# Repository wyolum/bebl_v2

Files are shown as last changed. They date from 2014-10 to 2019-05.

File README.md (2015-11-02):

bebl_v2
=======

"Bar End Brake Light" , redux. v2 of Justin's original BEBL with mods.

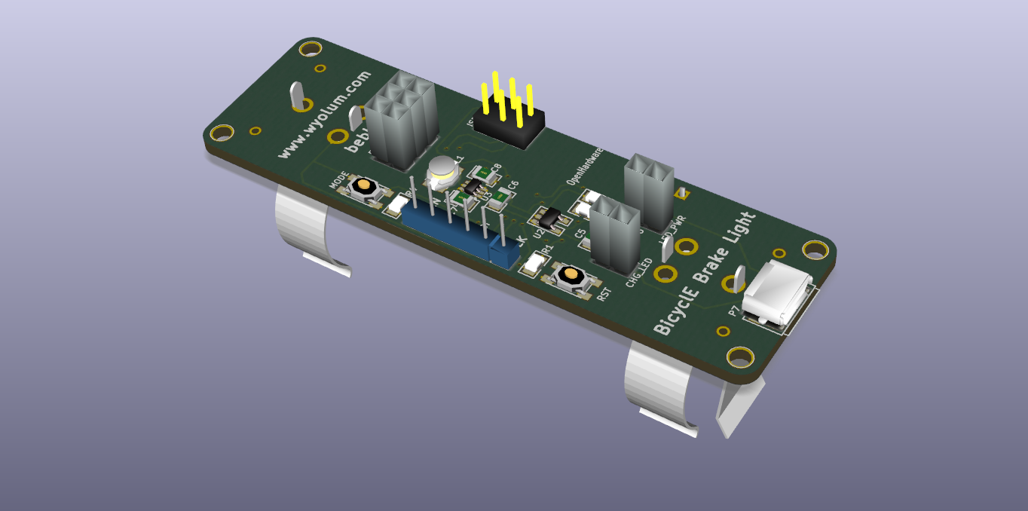
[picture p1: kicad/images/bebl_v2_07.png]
bebl main board


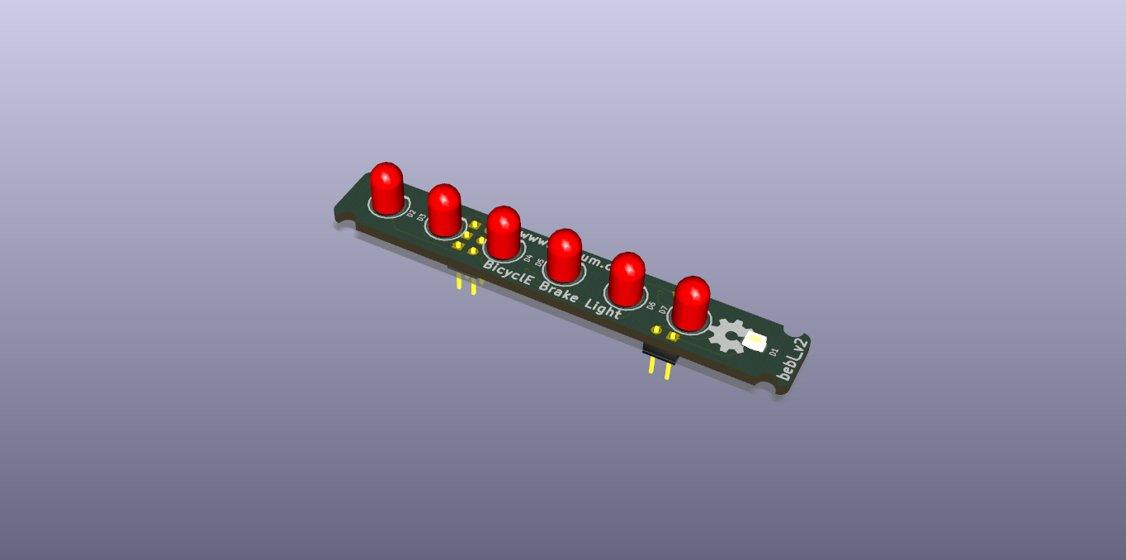
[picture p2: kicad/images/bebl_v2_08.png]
bebl LED board


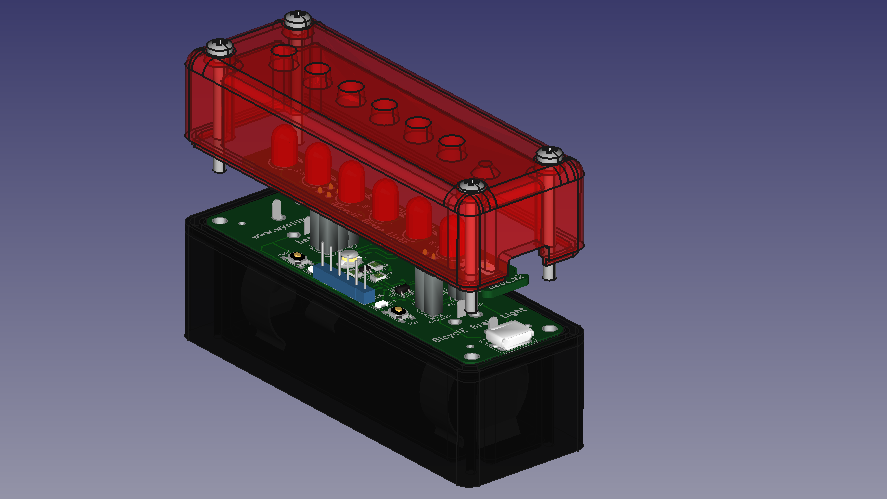
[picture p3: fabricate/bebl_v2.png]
bebl with 3D printed housing


License
-------
[CERN Open Hardware Licence v1.2 ]

[CERN Open Hardware Licence v1.2 ]:http://www.ohwr.org/attachments/2388/cern_ohl_v_1_2.txt

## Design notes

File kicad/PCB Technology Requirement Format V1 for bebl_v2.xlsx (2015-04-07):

深圳矽递科技有限公司Seeed Technology Inc.
PCB Technology Requirement Format
PCB Name & Version
PCB Material PCB板材： | (Rigid)FR－4
PCB Size PCB大小： | mm | ( 80 ) × ( 24 )
PCB Layer PCB层数： | 2
Thickness PCB厚度：
 |  | 1.6mm
Copper Weight铜厚： | 1oz
PCB Colour阻焊颜色： |  | White白色
Silkscreen字符颜色： |  | Black黑色
Pads Finished焊盘喷镀： | (Hasl-lead free)无铅喷锡
Via solder mask阻焊覆盖： |  | solder mask opening过孔开窗
Minimum trace/space (mm)最小线宽 | 0.178mm | Minimum hole size (mm)最小孔径 | 0.508mm
Special requirements特殊工艺： | Yes | (Put requirements here)
Comment: | PCB is in two parts 80 x 24 mm 74 x 11 mm

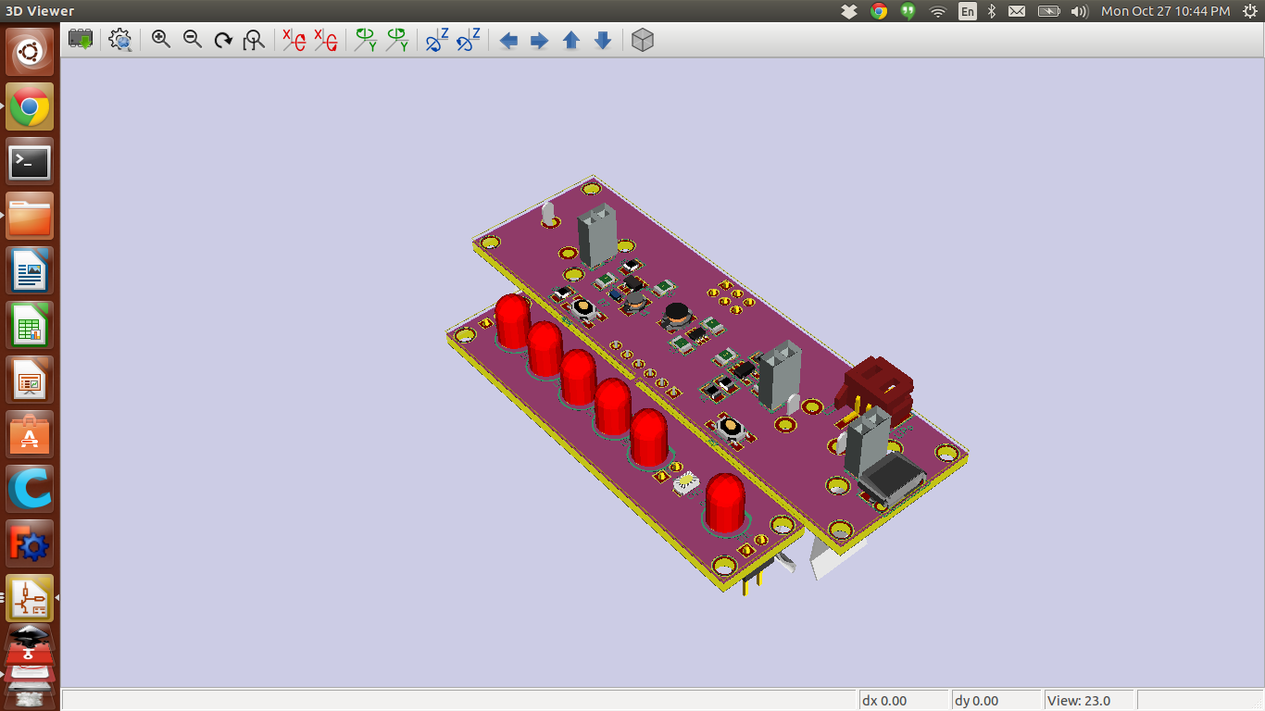
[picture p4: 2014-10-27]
kicad/images/bebl_v2_04.png

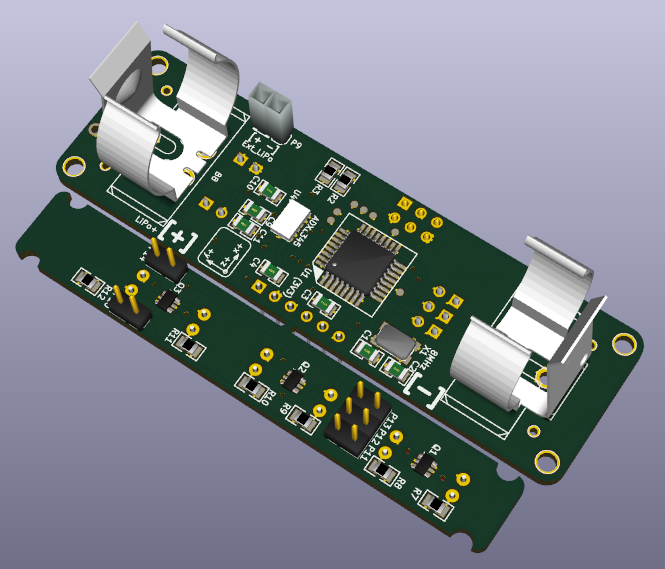
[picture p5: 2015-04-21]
kicad/images/bebl_v2_05.png

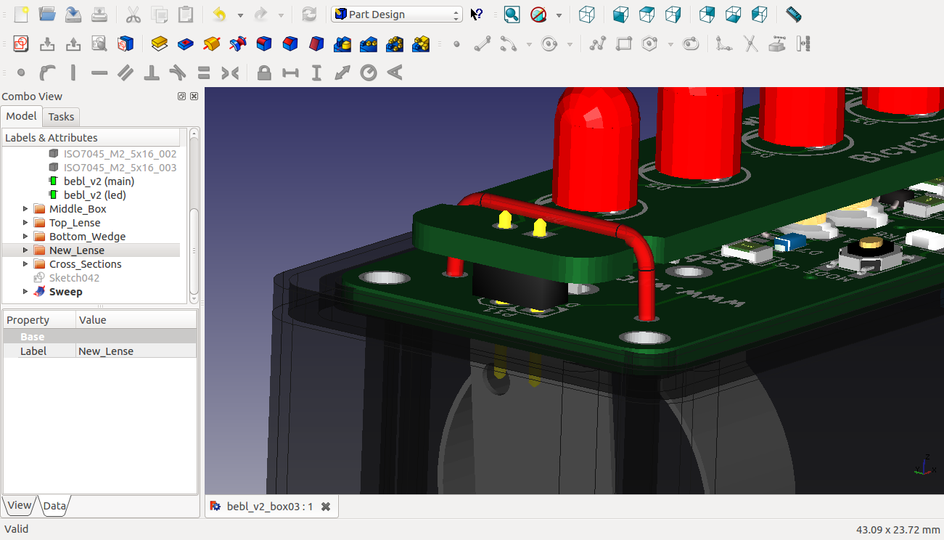
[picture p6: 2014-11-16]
kicad/images/bebl_v2_RedWireAnchor.png

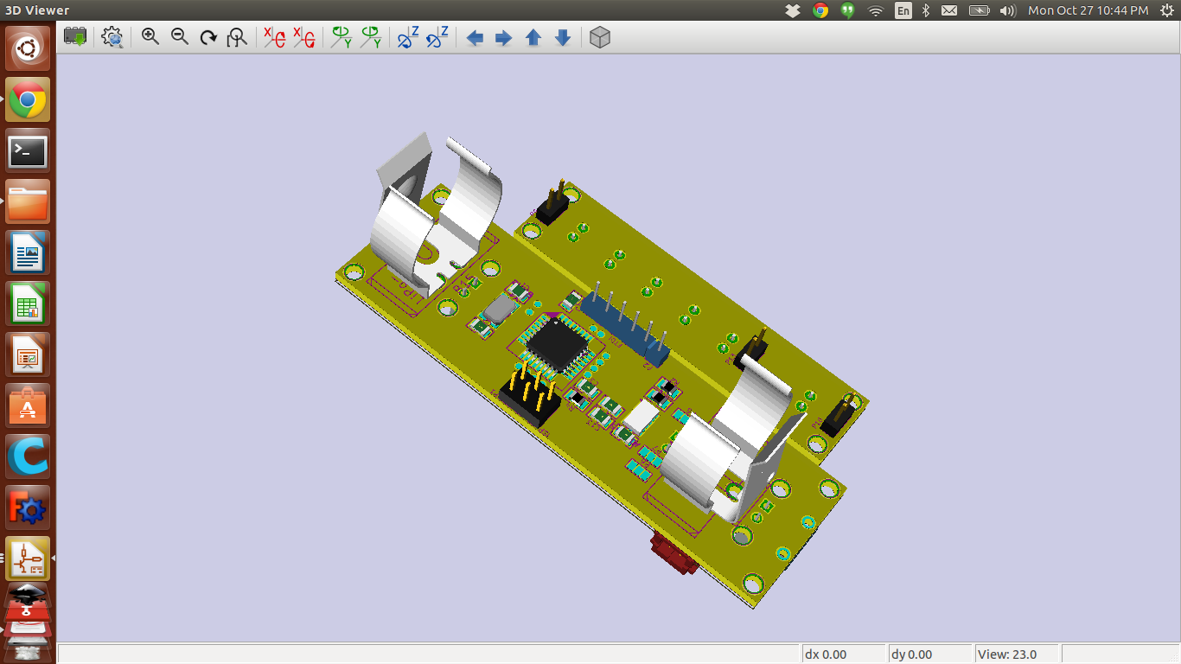
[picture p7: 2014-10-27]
kicad/images/bebl_v2_03.png

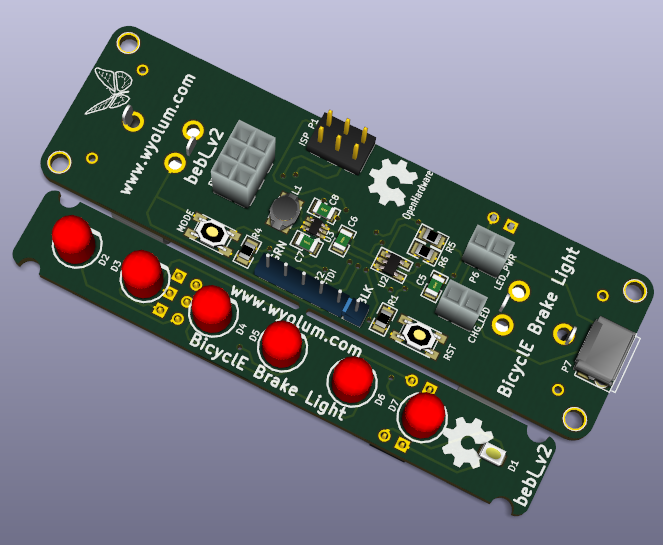
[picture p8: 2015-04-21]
kicad/images/bebl_v2_06.png

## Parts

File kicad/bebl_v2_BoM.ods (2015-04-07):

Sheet: Sheet1
Reference | Qty | Catalog | Description | Value | Package | Footprint | Manufacturer | Mfg. P/N | Distributor | Dist. P/N | Link | Price/1 | Price/100
 |  |  |  |  |  |  |  |  |  |  |  | 20.19 | 14.03 | 34.28 | 23.54
B8, B9 | 2 |  | BATTERY CLIP 18MM 18650 CELL | LiPo+ | PCB, Through Hole | batt_clip | Keystone Electronics | 54 | Digikey | KEY1007-ND | http://www.digikey.com/product-detail/en/54/KEY1007-ND/2254090 | 0.68 | 0.40 | 1.36 | 0.81
C1, C2 | 2 |  | CAP CER 22PF 100V 5% NP0 0805 | 22pF | 0805 (2012 Metric) | c_0805 | Samsung Electro-Mechanics America, Inc | CL21C220JCANNNC | Digikey | 1276-2607-1-ND | http://www.digikey.com/product-detail/en/CL21C220JCANNNC/1276-2607-1-ND/3890693 | 0.10 | 0.03 | 0.20 | 0.06
C3, C4, C11, C10 | 4 |  | CAP CER 0.1UF 25V 10% X7R 0805 | 100nF | 0805 (2012 Metric) | c_0805 | Samsung Electro-Mechanics America, Inc | CL21B104KACNNNC | Digikey | 1276-1099-1-ND | http://www.digikey.com/product-detail/en/CL21B104KACNNNC/1276-1099-1-ND/3889185 | 0.10 | 0.02 | 0.40 | 0.08
C5, C6 | 2 |  | CAP CER 4.7UF 10V 10% X7R 0805 | 4u7 | 0805 (2012 Metric) | c_0805 | Samsung Electro-Mechanics America, Inc | CL21B475KPFNNNE | Digikey | 1276-2972-1-ND | http://www.digikey.com/product-detail/en/CL21B475KPFNNNE/1276-2972-1-ND/3891058 | 0.20 | 0.07 | 0.40 | 0.14
C7, C8, C9 | 3 |  | CAP CER 10UF 16V 10% X7R 0805 | 10uF | 0805 (2012 Metric) | c_0805 | Samsung Electro-Mechanics America, Inc | CL21B106KOQNNNE | Digikey | 1276-2872-1-ND | http://www.digikey.com/product-detail/en/CL21B106KOQNNNE/1276-2872-1-ND/3890958 | 0.30 | 0.12 | 0.90 | 0.37
D1 | 1 |  | LED CHIPLED 588NM YLW 0805 SMD | CHG | 0805 (2012 Metric) | LED-0805 | OSRAM Opto Semiconductors Inc | LY R976-PS-36 | Digikey | 475-2560-1-ND | http://www.digikey.com/product-detail/en/LY%20R976-PS-36/475-2560-1-ND/1802687 | 0.09 | 0.06 | 0.09 | 0.06
D2, D3, D4, D5, D6, D7 | 6 |  | LED, 5mm, high intensity | LED_P, LED_D, LED_B | 5mm Through Hole | LED-5MM | CHINA YOUNG SUN LED TECHNOLOGY CO., LTD. | YSL-R531R3C-A13 | Sparkfun | COM-00528 | https://www.sparkfun.com/products/528 | 0.95 | 0.76 | 5.70 | 4.56
L1 | 1 |  | FIXED IND 4.7uH 1.5A 144 mOHM | 4u7 | 1212 (3030 Metric) | Inductor_LQH3NPN | Murata Electronics North America | LQH3NPN4R7MJRL | Digikey | 490-9579-1-ND | http://www.digikey.com/product-detail/en/LQH3NPN4R7MJRL/490-9579-1-ND/4864756 | 0.48 | 0.31 | 0.48 | 0.31
P1 | 1 |  | CONN HEADER 6POS .100 STR TIN | ISP | Dual row, 0.1”, Male Header | Dual row, 0.1”, Male Header | FCI | 67996-406HLF | Digikey | 609-3218-ND | http://www.digikey.com/product-detail/en/67996-406HLF/609-3218-ND/1878478 | 0.26 | 0.17 | 0.26 | 0.17
P2,P10,P11,P12,P13,P14 | 6 |  | CONN HEADER .100" SNGL STR 40POS | FTDI,LED_CHG,LED_1,LED_2,LED_3,LED_PWR | Single row, 0.1”, Male Header | Single row, 0.1”, Male Header | Sullins Connector Solutions | PREC040SAAN-RC | Digikey | S1012EC-40-ND | http://www.digikey.com/product-detail/en/PREC040SAAN-RC/S1012EC-40-ND/2774814 | 0.56 | 0.42 | 3.36 | 2.49
P3,P4,P5,P6,P8,P9 | 6 |  | CONN SOCKET SGL VERT 2POS GOLD | LED_CHG,LED_1,LED_2,LED_3,LED_PWR,Ext_Lipo | Single row, 0.1”, Female Socket | Single row, 0.1”, Female Socket | 3M | 960102-6202-AR | Digikey | 3M9513-ND | http://www.digikey.com/product-detail/en/960102-6202-AR/3M9513-ND/2071554 | 0.51 | 0.37 | 3.06 | 2.21
P7 | 1 |  | CONN USB MICRO B RECPT SMT R/A | USB-Micro | Surface Mount, Right Angle, Horizontal | Surface Mount, Right Angle, Horizontal | SunTech | ST-USB-001G | seeed Studio | 320010000 | http://www.seeedstudio.com/depot/index.php?main_page=opl_info&opl_id=331 | 0.46 | 0.30 | 0.46 | 0.30
Q1, Q2, Q3 | 3 |  | TRANS 2NPN 45V 0.1A SOT363 | BC847 | 6-TSSOP, SC-88, SOT-363 | SOT23-6 | ON Semiconductor | TRANS 2NPN 45V 0.1A SOT363 | Digikey | BC847BDW1T3GOSCT-ND | http://www.digikey.com/product-detail/en/BC847BDW1T3G/BC847BDW1T3GOSCT-ND/2120552 | 0.24 | 0.12 | 0.72 | 0.37
R1,R2,R3,R4 | 4 |  | RES 10K OHM 1/8W 1% 0805 | 10k | 0805 (2012 Metric) | r_0805 | Stackpole Electronics Inc | RMCF0805FT10K0 | Digikey | RMCF0805FT10K0CT-ND | http://www.digikey.com/product-detail/en/RMCF0805FT10K0/RMCF0805FT10K0CT-ND/1942435 | 0.10 | 0.01 | 0.40 | 0.05
R5 | 1 |  | RES 150 OHM 1/8W 1% 0805 | 150E | 0805 (2012 Metric) | r_0805 | Stackpole Electronics Inc | RMCF0805FT150R | Digikey | RMCF0805FT150RCT-ND | http://www.digikey.com/product-detail/en/RMCF0805FT150R/RMCF0805FT150RCT-ND/1942337 | 0.10 | 0.01 | 0.10 | 0.01
R6 | 1 |  | RES 2K OHM 1/8W 1% 0805 | 2k | 0805 (2012 Metric) | r_0805 | Stackpole Electronics Inc | RMCF0805FT2K00 | Digikey | RMCF0805FT2K00CT-ND | http://www.digikey.com/product-detail/en/RMCF0805FT2K00/RMCF0805FT2K00CT-ND/1942383 | 0.10 | 0.01 | 0.10 | 0.01
R7, R8, R9, R10, R11, R12 | 6 |  | RES SMD 22 OHM 1% 1/8W 0805 |  | 0805 (2012 Metric) | r_0805 | Stackpole Electronics Inc | RMCF0805FT22R0 | Digikey | RMCF0805FT22R0CT-ND | http://www.digikey.com/product-detail/en/RMCF0805FT22R0/RMCF0805FT22R0CT-ND/2418324 | 0.10 | 0.01 | 0.60 | 0.07
SW1, SW2 | 2 |  | SWITCH TACTILE SPST-NO 0.02A 15V | RST, MODE | 4.70mm x 3.50mm | Switch_SMT | Panasonic Electronic Components | EVQ-P2402M | Digikey | P11080SCT-ND | http://www.digikey.com/product-detail/en/EVQ-P2402M/P11080SCT-ND/304157 | 0.83 | 0.63 | 1.66 | 1.25
U1 | 1 |  | IC MCU 8BIT 32KB FLASH 32TQFP | ATMEGA328P | 32-TQFP | TQFP32 | Atmel | ATMEGA328P-AU | Digikey | ATMEGA328P-AU-ND | http://www.digikey.com/product-detail/en/ATMEGA328P-AU/ATMEGA328P-AU-ND/1832260 | 3.61 | 2.64 | 3.61 | 2.64
U2 | 1 |  | IC CONTROLLR LI-ION 4.2V SOT23-5 | MCP73831 | SC-74A, SOT-753 | SOT23-5 | Microchip Technology | MCP73831T-2ACI/OT | Digikey | MCP73831T-2ACI/OTCT-ND | http://www.digikey.com/product-detail/en/MCP73831T-2ACI%2FOT/MCP73831T-2ACI%2FOTCT-ND/1979802 | 0.67 | 0.42 | 0.67 | 0.42
U3 | 1 |  | IC REG BOOST SYNC 3.3V SC70-6 | TPS61221DCK | 6-TSSOP, SC-88, SOT-363 | SOT23-6_LDO | Texas Instruments | TPS61221DCKT | Digikey | 296-24171-1-ND | http://www.digikey.com/product-search/en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 | 1.61 | 1.12 | 1.61 | 1.12
U4 | 1 |  | IC ACCEL SPI/I2C 3AX 3G 14LGA | ADXL345 | 14-VFLGA | ADXL345 | Analog Devices Inc | ADXL345BCCZ | Digikey | ADXL345BCCZ-ND | http://www.digikey.com/product-detail/en/ADXL345BCCZ/ADXL345BCCZ-ND/2034829 | 7.32 | 5.41 | 7.32 | 5.41
X1 | 1 |  | CRYSTAL 8MHZ 18PF SMD | 8MHz | 4-SMD, No Lead (DFN, LCC) | Xtal_SMD4 | TXC CORPORATION | 7B-8.000MAAJ-T | Digikey | 887-1452-1-ND | http://www.digikey.com/product-detail/en/7B-8.000MAAJ-T/887-1452-1-ND/2627020 | 0.82 | 0.60 | 0.82 | 0.60

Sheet: PCB
Id | Designator | Package | Quantity | Designation
1 | B8 | batt_clip | 1 | LiPo
2 | B9 | batt_clip | 1 | LiPo-
3 | C1,C2 | c_0805 | 2 | 22p
4 | C3,C4 | c_0805 | 2 | 100n
5 | C5,C6 | c_0805 | 2 | 4u7
6 | C7,C8,C9 | c_0805 | 3 | 10uF
7 | C11,C10 | c_0805 | 2 | 100nF
8 | D1 | LED-0805 | 1 | CHG
9 | D2,D3,D5,D6 | LED-5MM | 4 | LED_P
10 | D4 | LED-5MM | 1 | LED_D
11 | D7 | LED-5MM | 1 | LED_B
12 | L1 | Inductor_LQH3NPN | 1 | 4u7
13 | P1 | Header_3x2_ISP | 1 | ISP
14 | P2 | PIN_ARRAY-6X1 | 1 | FTDI
15 | P3 | pin_socket_2 | 1 | LED_1
16 | P4 | pin_socket_2 | 1 | LED_2
17 | P5 | pin_socket_2 | 1 | LED_3
18 | P6 | pin_socket_2 | 1 | LED_PWR
19 | P7 | USB_B_Micro | 1 | USB-Micro
20 | P8 | pin_socket_2 | 1 | CHG_LED
21 | P9 | pin_socket_2 | 1 | Ext_LiPo
22 | P10 | pin_strip_2 | 1 | LED_CHG
23 | P11 | pin_strip_2 | 1 | LED_1
24 | P12 | pin_strip_2 | 1 | LED_2
25 | P13 | pin_strip_2 | 1 | LED_3
26 | P14 | pin_strip_2 | 1 | LED_PWR
27 | Q1,Q2,Q3 | SOT23-6 | 3 | BC847BDW1T1G
28 | R1,R2,R3,R4 | r_0805 | 4 | 10k
29 | R5 | r_0805 | 1 | 150E
30 | R6 | r_0805 | 1 | 2k
31 | R7,R8,R9,R10,R11,R12 | r_0805 | 6 | 22E
32 | SW1 | Switch_SMT | 1 | RST
33 | SW2 | Switch_SMT | 1 | MODE
34 | U1 | TQFP32 | 1 | ATMEGA328P
35 | U2 | SOT23-5 | 1 | MCP73831
36 | U3 | SOT23-6_LDO | 1 | TPS61221DCK
37 | U4 | ADXL345 | 1 | ADXL345
38 | X1 | Xtal_SMD4 | 1 | 8MHz
39 | B1,B2,B3,B4,B5,B6,B7 | breakout_smd | 7 | I/O
40 | G***,G*** | OSHW_6mm | 2 | LOGO
41 | G1 | Logo-WL3 | 1 | Logo-WL3
42 | SC1,SC2,SC3,SC4,SC5,SC6,SC7,SC8 | screw_3mm | 8 | SCREW

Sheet: SCH
Reference | Value | Footprint
B8 | LiPo | bebl_v2_pretty:batt_clip
B9 | LiPo- | bebl_v2_pretty:batt_clip
C1 | 22p | bebl_v2_pretty:c_0805
C2 | 22p | bebl_v2_pretty:c_0805
C3 | 100n | bebl_v2_pretty:c_0805
C4 | 100n | bebl_v2_pretty:c_0805
C5 | 4u7 | bebl_v2_pretty:c_0805
C6 | 4u7 | bebl_v2_pretty:c_0805
C7 | 10uF | bebl_v2_pretty:c_0805
C8 | 10uF | bebl_v2_pretty:c_0805
C9 | 10uF | bebl_v2_pretty:c_0805
C10 | 100nF | bebl_v2_pretty:c_0805
C11 | 100nF | bebl_v2_pretty:c_0805
D1 | CHG | bebl_v2_pretty:LED-0805
D2 | LED_P | bebl_v2_pretty:LED-5MM
D3 | LED_P | bebl_v2_pretty:LED-5MM
D4 | LED_D | bebl_v2_pretty:LED-5MM
D5 | LED_P | bebl_v2_pretty:LED-5MM
D6 | LED_P | bebl_v2_pretty:LED-5MM
D7 | LED_B | bebl_v2_pretty:LED-5MM
L1 | 4u7 | bebl_v2_pretty:Inductor_LQH3NPN
P1 | ISP | bebl_v2_pretty:Header_3x2_ISP
P2 | FTDI | bebl_v2_pretty:PIN_ARRAY-6X1
P3 | LED_1 | bebl_v2_pretty:pin_socket_2
P4 | LED_2 | bebl_v2_pretty:pin_socket_2
P5 | LED_3 | bebl_v2_pretty:pin_socket_2
P6 | LED_PWR | bebl_v2_pretty:pin_socket_2
P7 | USB-Micro | bebl_v2_pretty:USB_B_Micro
P8 | CHG_LED | bebl_v2_pretty:pin_socket_2
P9 | Ext_LiPo | bebl_v2_pretty:pin_socket_2
P10 | LED_CHG | bebl_v2_pretty:pin_strip_2
P11 | LED_1 | bebl_v2_pretty:pin_strip_2
P12 | LED_2 | bebl_v2_pretty:pin_strip_2
P13 | LED_3 | bebl_v2_pretty:pin_strip_2
P14 | LED_PWR | bebl_v2_pretty:pin_strip_2
Q1 | BC847BDW1T1G | bebl_v2_pretty:SOT23-6
Q2 | BC847BDW1T1G | bebl_v2_pretty:SOT23-6
Q3 | BC847BDW1T1G | bebl_v2_pretty:SOT23-6
R1 | 10k | bebl_v2_pretty:r_0805
R2 | 10k | bebl_v2_pretty:r_0805
R3 | 10k | bebl_v2_pretty:r_0805
R4 | 10k | bebl_v2_pretty:r_0805
R5 | 150E | bebl_v2_pretty:r_0805
R6 | 2k | bebl_v2_pretty:r_0805
R7 | 22E | bebl_v2_pretty:r_0805
R8 | 22E | bebl_v2_pretty:r_0805
R9 | 22E | bebl_v2_pretty:r_0805
R10 | 22E | bebl_v2_pretty:r_0805
R11 | 22E | bebl_v2_pretty:r_0805
R12 | 22E | bebl_v2_pretty:r_0805
SW1 | RST | bebl_v2_pretty:Switch_SMT
SW2 | MODE | bebl_v2_pretty:Switch_SMT
U1 | ATMEGA328P | bebl_v2_pretty:TQFP32
U2 | MCP73831 | bebl_v2_pretty:SOT23-5
U3 | TPS61221DCK | bebl_v2_pretty:SOT23-6_LDO
U4 | ADXL345 | bebl_v2_pretty:ADXL345
X1 | 8MHz | bebl_v2_pretty:Xtal_SMD4
B1 | I/O | bebl_v2_pretty:breakout_smd
B2 | I/O | bebl_v2_pretty:breakout_smd
B3 | I/O | bebl_v2_pretty:breakout_smd
B4 | I/O | bebl_v2_pretty:breakout_smd
B5 | I/O | bebl_v2_pretty:breakout_smd
B6 | I/O | bebl_v2_pretty:breakout_smd
B7 | I/O | bebl_v2_pretty:breakout_smd
SC1 | SCREW | bebl_v2_pretty:screw_3mm
SC2 | SCREW | bebl_v2_pretty:screw_3mm
SC3 | SCREW | bebl_v2_pretty:screw_3mm
SC4 | SCREW | bebl_v2_pretty:screw_3mm
SC5 | SCREW | bebl_v2_pretty:screw_3mm
SC6 | SCREW | bebl_v2_pretty:screw_3mm
SC7 | SCREW | bebl_v2_pretty:screw_3mm
SC8 | SCREW | bebl_v2_pretty:screw_3mm

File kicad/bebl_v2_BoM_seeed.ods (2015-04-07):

Electronic Engineering BOM List
Product Name : bebl_v2 (BicyclE Brake Light)
Version：V2.0
Issue Date：04/Feb/2015
Item No. (序号) | Reference Des (上件位置) | Qty (用量) | Catalog (分类） | Part_Description (规格描述) | Part_Value （元件值） | Part_Package （元件封装） | Manufacturers Name (使用厂牌名称) | Manufacturers Part No. (使用厂牌型号) | Distributors Name （供应商名称） | Distributors Part No. (供貨商型号) | Unit Price （单价） | Price Break To Use （价格分段的购买量） | Notes/Remark （备注）
Example（填写范例）
1 | B8,B9 | 2 | Connector | BATTERY CLIP 18MM 18650 CELL | LiPo+, LiPo- | PCB, Through Hole | Keystone Electronics | 54 | Digikey | KEY1007-ND |  |  | http://www.digikey.com/product-detail/en/54/KEY1007-ND/2254090
2 | C1,C2 | 2 | Capacitor | CAP CER 22PF 100V 5% NP0 0805 | 22pF | 0805 (2012 Metric) | Samsung Electro-Mechanics America, Inc | CL21C220JCANNNC | Digikey | 1276-2607-1-ND |  |  | http://www.digikey.com/product-detail/en/CL21C220JCANNNC/1276-2607-1-ND/3890693
3 | C3,C4,C11,C10 | 4 | Capacitor | CAP CER 0.1UF 25V 10% X7R 0805 | 100nF | 0805 (2012 Metric) | Samsung Electro-Mechanics America, Inc | CL21B104KACNNNC | Digikey | 1276-1099-1-ND |  |  | http://www.digikey.com/product-detail/en/CL21B104KACNNNC/1276-1099-1-ND/3889185
4 | C5,C6 | 2 | Capacitor | CAP CER 4.7UF 10V 10% X7R 0805 | 4u7 | 0805 (2012 Metric) | Samsung Electro-Mechanics America, Inc | CL21B475KPFNNNE | Digikey | 1276-2972-1-ND |  |  | http://www.digikey.com/product-detail/en/CL21B475KPFNNNE/1276-2972-1-ND/3891058
5 | C7,C8,C9 | 3 | Capacitor | CAP CER 10UF 16V 10% X7R 0805 | 10uF | 0805 (2012 Metric) | Samsung Electro-Mechanics America, Inc | CL21B106KOQNNNE | Digikey | 1276-2872-1-ND |  |  | http://www.digikey.com/product-detail/en/CL21B106KOQNNNE/1276-2872-1-ND/3890958
6 | D1 | 1 | Diode | LED CHIPLED 588NM YLW 0805 SMD | CHG | 0805 (2012 Metric) | OSRAM Opto Semiconductors Inc | LY R976-PS-36 | Digikey | 475-2560-1-ND |  |  | http://www.digikey.com/product-detail/en/LY%20R976-PS-36/475-2560-1-ND/1802687
7 | D2,D3,D4,D5,D6,D7 | 6 | Diode | LED, 5mm, high intensity | LED_P, LED_D, LED_B | 5mm Through Hole | CHINA YOUNG SUN LED TECHNOLOGY CO., LTD. | YSL-R531R3C-A13 | Sparkfun | COM-00528 |  |  | https://www.sparkfun.com/products/528
8 | L1 | 1 | OTHER | FIXED IND 4.7uH 1.5A 144 mOHM | 4u7 | 1212 (3030 Metric) | Murata Electronics North America | LQH3NPN4R7MJRL | Digikey | 490-9579-1-ND |  |  | http://www.digikey.com/product-detail/en/LQH3NPN4R7MJRL/490-9579-1-ND/4864756
9 | P1 | 1 | Connector | CONN HEADER 6POS .100 STR TIN | ISP | Dual row, 0.1”, Male Header | FCI | 67996-406HLF | Digikey | 609-3218-ND |  |  | http://www.digikey.com/product-detail/en/67996-406HLF/609-3218-ND/1878478
10 | P2,P10,P11,P12,P13,P14 | 6 | Connector | CONN HEADER .100" SNGL STR 40POS | FTDI,LED_CHG,LED_1,LED_2,LED_3,LED_PWR | Single row, 0.1”, Male Header | Sullins Connector Solutions | PREC040SAAN-RC | Digikey | S1012EC-40-ND |  |  | http://www.digikey.com/product-detail/en/PREC040SAAN-RC/S1012EC-40-ND/2774814
11 | P3,P4,P5,P6,P8 | 5 | Connector | CONN SOCKET SGL VERT 2POS GOLD | LED_CHG,LED_1,LED_2,LED_3,LED_PWR | Single row, 0.1”, Female Socket | 3M | 960102-6202-AR | Digikey | 3M9513-ND |  |  | http://www.digikey.com/product-detail/en/960102-6202-AR/3M9513-ND/2071554
12 | P7 | 1 | Connector | CONN USB MICRO B RECPT SMT R/A | USB-Micro | Surface Mount, Right Angle, Horizontal | SunTech | ST-USB-001G | seeed Studio | 320010000 |  |  | http://www.seeedstudio.com/depot/index.php?main_page=opl_info&opl_id=331
13 | Q1,Q2,Q3 | 3 | Transistor | TRANS 2NPN 45V 0.1A SOT363 | BC847 | 6-TSSOP, SC-88, SOT-363 | ON Semiconductor | TRANS 2NPN 45V 0.1A SOT363 | Digikey | BC847BDW1T3GOSCT-ND |  |  | http://www.digikey.com/product-detail/en/BC847BDW1T3G/BC847BDW1T3GOSCT-ND/2120552
14 | R1,R2,R3,R4 | 4 | Resister | RES 10K OHM 1/8W 1% 0805 | 10k | 0805 (2012 Metric) | Stackpole Electronics Inc | RMCF0805FT10K0 | Digikey | RMCF0805FT10K0CT-ND |  |  | http://www.digikey.com/product-detail/en/RMCF0805FT10K0/RMCF0805FT10K0CT-ND/1942435
15 | R5 | 1 | Resister | RES 150 OHM 1/8W 1% 0805 | 150E | 0805 (2012 Metric) | Stackpole Electronics Inc | RMCF0805FT150R | Digikey | RMCF0805FT150RCT-ND |  |  | http://www.digikey.com/product-detail/en/RMCF0805FT150R/RMCF0805FT150RCT-ND/1942337
16 | R6 | 1 | Resister | RES 2K OHM 1/8W 1% 0805 | 2k | 0805 (2012 Metric) | Stackpole Electronics Inc | RMCF0805FT2K00 | Digikey | RMCF0805FT2K00CT-ND |  |  | http://www.digikey.com/product-detail/en/RMCF0805FT2K00/RMCF0805FT2K00CT-ND/1942383
17 | R7,R8,R9,R10,R11,R12 | 6 | Resister | RES SMD 22 OHM 1% 1/8W 0805 | 22E | 0805 (2012 Metric) | Stackpole Electronics Inc | RMCF0805FT22R0 | Digikey | RMCF0805FT22R0CT-ND |  |  | http://www.digikey.com/product-detail/en/RMCF0805FT22R0/RMCF0805FT22R0CT-ND/2418324
18 | SW1,SW2 | 2 | OTHER | SWITCH TACTILE SPST-NO 0.02A 15V | RST, MODE | 4.70mm x 3.50mm | Panasonic Electronic Components | EVQ-P2402M | Digikey | P11080SCT-ND |  |  | http://www.digikey.com/product-detail/en/EVQ-P2402M/P11080SCT-ND/304157
19 | U1 | 1 | IC | IC MCU 8BIT 32KB FLASH 32TQFP | ATMEGA328P | 32-TQFP | Atmel | ATMEGA328P-AU | Digikey | ATMEGA328P-AU-ND |  |  | http://www.digikey.com/product-detail/en/ATMEGA328P-AU/ATMEGA328P-AU-ND/1832260
20 | U2 | 1 | IC | IC CONTROLLR LI-ION 4.2V SOT23-5 | MCP73831 | SC-74A, SOT-753 | Microchip Technology | MCP73831T-2ACI/OT | Digikey | MCP73831T-2ACI/OTCT-ND |  |  | http://www.digikey.com/product-detail/en/MCP73831T-2ACI%2FOT/MCP73831T-2ACI%2FOTCT-ND/1979802
21 | U3 | 1 | IC | IC REG BOOST SYNC 3.3V SC70-6 | TPS61221DCK | 6-TSSOP, SC-88, SOT-363 | Texas Instruments | TPS61221DCKT | Digikey | 296-24171-1-ND |  |  | http://www.digikey.com/product-search/en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
22 | U4 | 1 | IC | IC ACCEL SPI/I2C 3AX 3G 14LGA | ADXL345 | 14-VFLGA | Analog Devices Inc | ADXL345BCCZ | Digikey | ADXL345BCCZ-ND |  |  | http://www.digikey.com/product-detail/en/ADXL345BCCZ/ADXL345BCCZ-ND/2034829
23 | X1 | 1 | OTHER | CRYSTAL 8MHZ 18PF SMD | 8MHz | 4-SMD, No Lead (DFN, LCC) | TXC CORPORATION | 7B-8.000MAAJ-T | Digikey | 887-1452-1-ND |  |  | http://www.digikey.com/product-detail/en/7B-8.000MAAJ-T/887-1452-1-ND/2627020
1. Recommended Distributor: Digi-Key, Mouser, Avnet Express, Farnell.
2. Catalog: Capacitor,Resister,Diode,Connector,Transistor,IC,PROTECTOR CATEGORY,OTHER
3. Required Fields: Item No, Reference Des, Qty, Catalog, Part_Value, Part Package
Optional Fields: Part_Description, Manufacturers Name, Manufacturers Part No, Distributors Name, Distributors Part No, Unit Cost, Price break to use, Notes/Remark

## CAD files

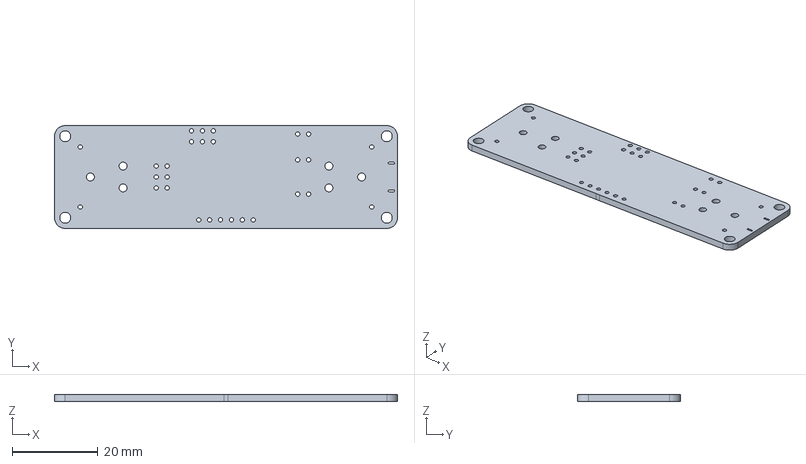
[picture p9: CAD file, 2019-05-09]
fabricate/bebl_v2_main.step
80.0 x 24.0 x 1.60 mm
female_pcb_pin_02 x 6
C0805 x 11
inductor_smd_do3316p
pins_array_6x1
r_0805 x 6
smd_push2 x 2
tqfp32
LGA_adxl345
SOT23_5 x 2
crystal_4pins_smd
pin_strip_3x2
smt_batt_clip x 2
usb_B_micro_smd

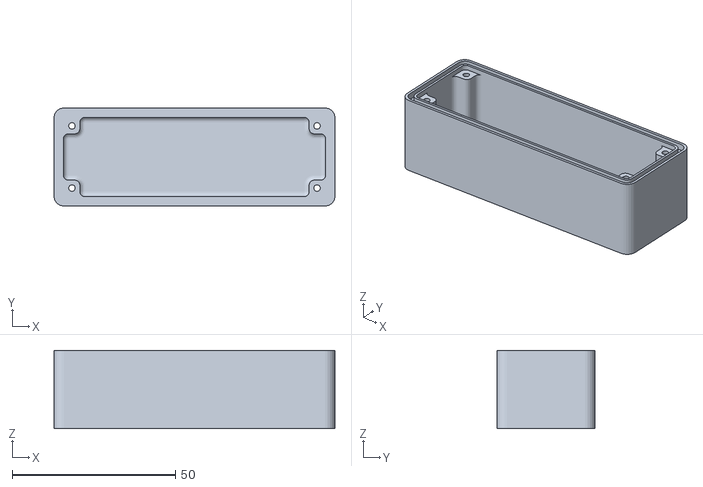
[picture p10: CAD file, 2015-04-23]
fabricate/mainbox.stl
86.0 x 30.0 x 24.0

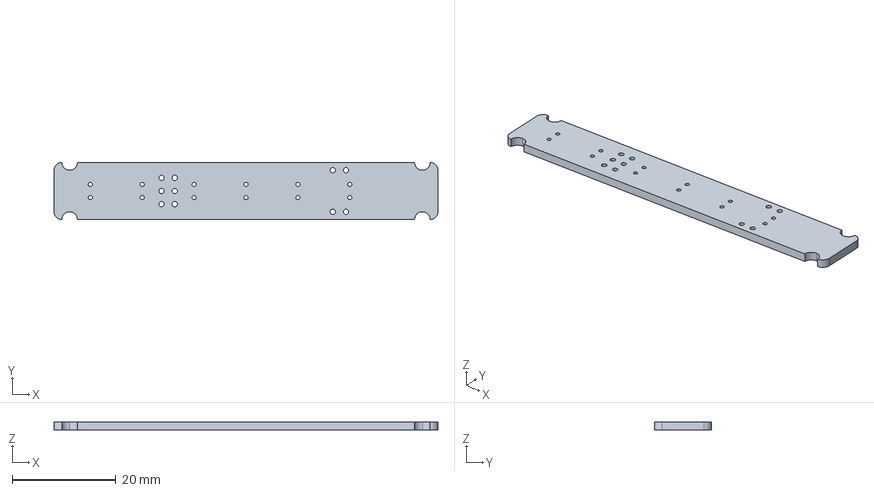
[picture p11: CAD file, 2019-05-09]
fabricate/bebl_v2_led.step
74.0 x 11.0 x 1.60 mm
pin_strip_2 x 5
r_0805 x 6
led5_vertical x 6
cree_clm3c
SOT23_5 x 3

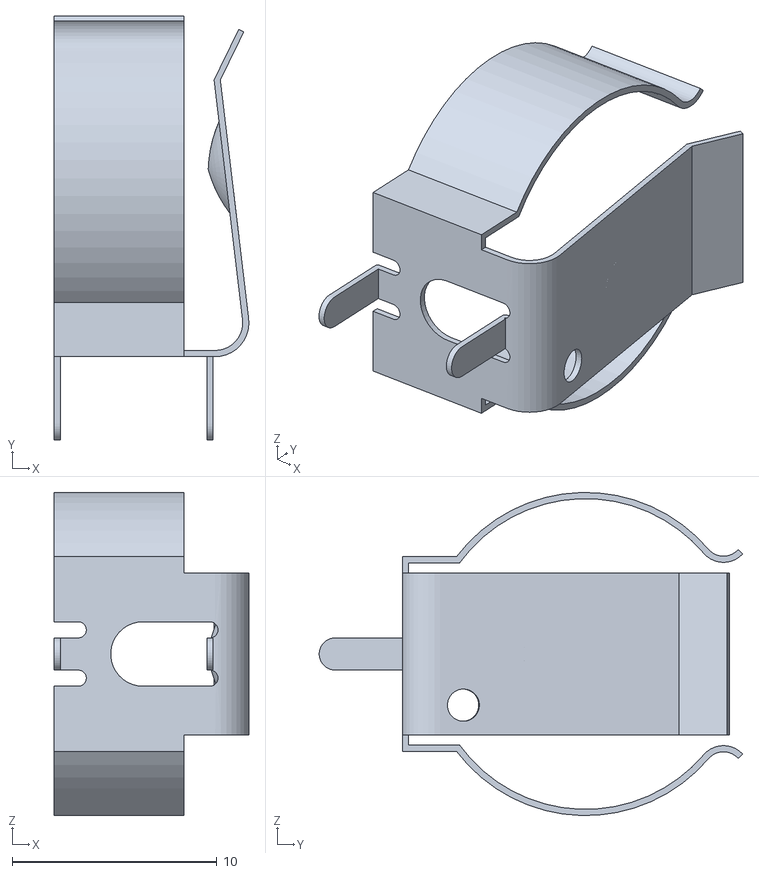
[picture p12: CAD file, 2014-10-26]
kicad/3d_modules/smt_batt_clip.stl
9.52 x 20.7 x 15.8

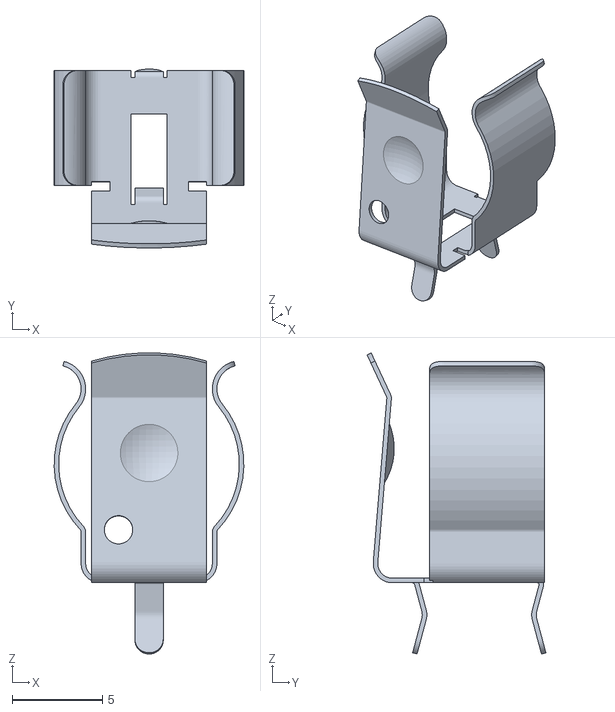
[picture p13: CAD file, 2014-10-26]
kicad/3d_modules/smt_batt_clip_Keystone 82.stl
10.5 x 9.89 x 16.6

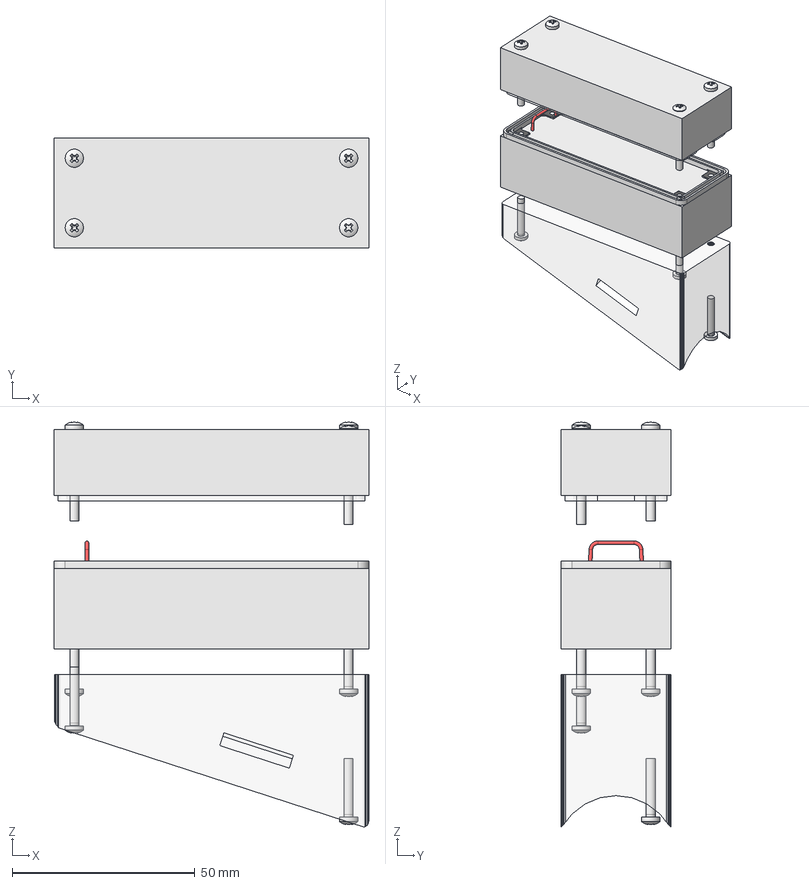
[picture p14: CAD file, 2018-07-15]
fabricate/bebl_v2_box03.fcstd
86.0 x 30.0 x 110.7 mm
TopCover
MainBox
ISO7045_M2_5x16_
ISO7045_M2_5x16_001
ISO7045_M2_5x16_002
ISO7045_M2_5x16_003
ISO7045_M2_5x25_
ISO7045_M2_5x25_001
ISO7045_M2_5x25_002
ISO7045_M2_5x25_003
Wedge

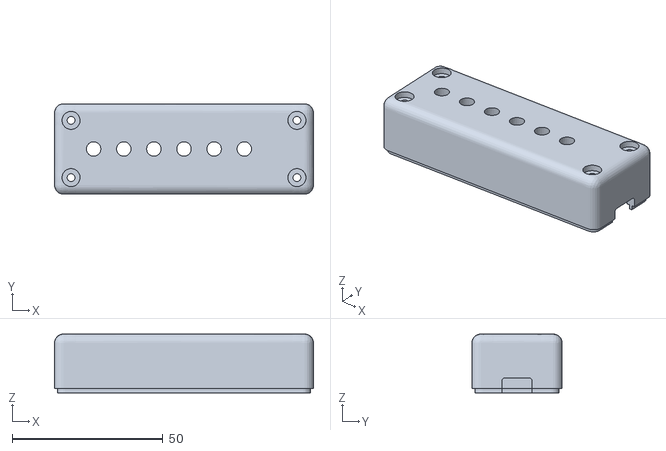
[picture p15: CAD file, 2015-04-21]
fabricate/topcover.stl
86.0 x 30.0 x 19.5

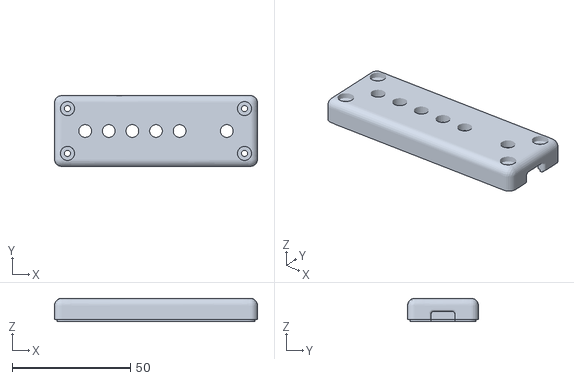
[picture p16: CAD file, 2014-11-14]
fabricate/new_topcover.stl
86.0 x 30.0 x 9.80

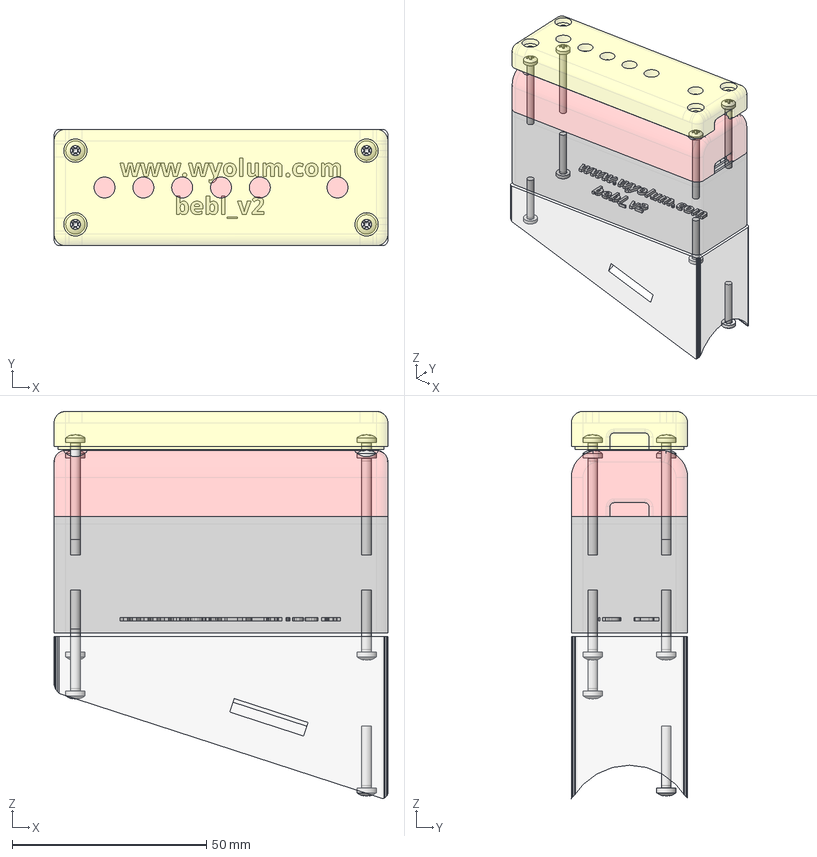
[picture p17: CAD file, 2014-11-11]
fabricate/bebl_v2_box02.fcstd
86.0 x 30.0 x 99.7 mm
ISO7045_M2_5x25_
ISO7045_M2_5x25_001
ISO7045_M2_5x25_002
ISO7045_M2_5x25_003
ISO7045_M2_5x16_
ISO7045_M2_5x16_001
ISO7045_M2_5x16_002
ISO7045_M2_5x16_003
MiddleBox
Lense
Wedge
NewTopLense

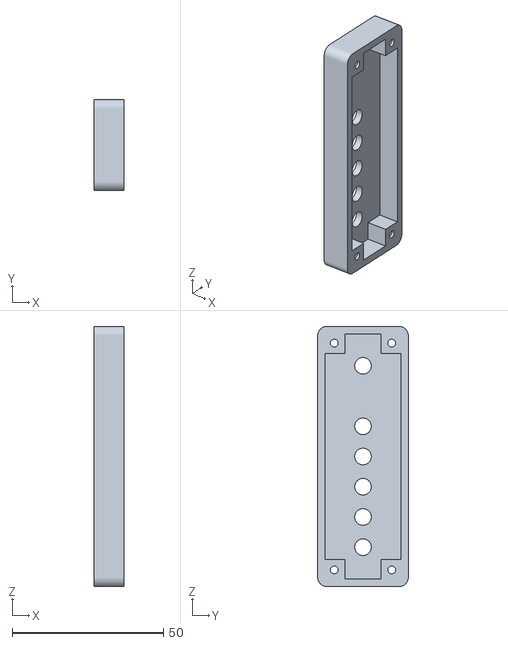
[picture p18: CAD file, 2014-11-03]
fabricate/jcover.stl
10.0 x 30.0 x 86.0

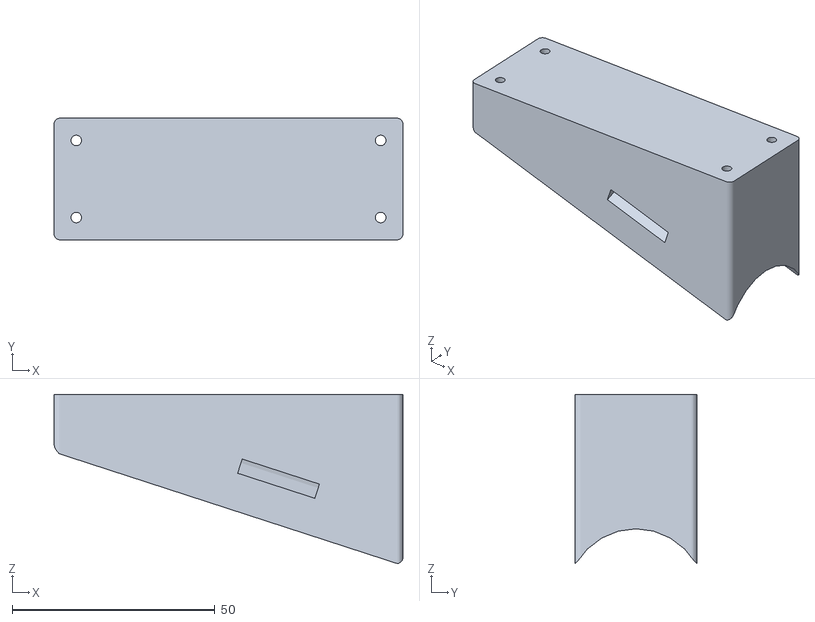
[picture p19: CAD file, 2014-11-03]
fabricate/wedge.stl
86.0 x 30.0 x 41.7

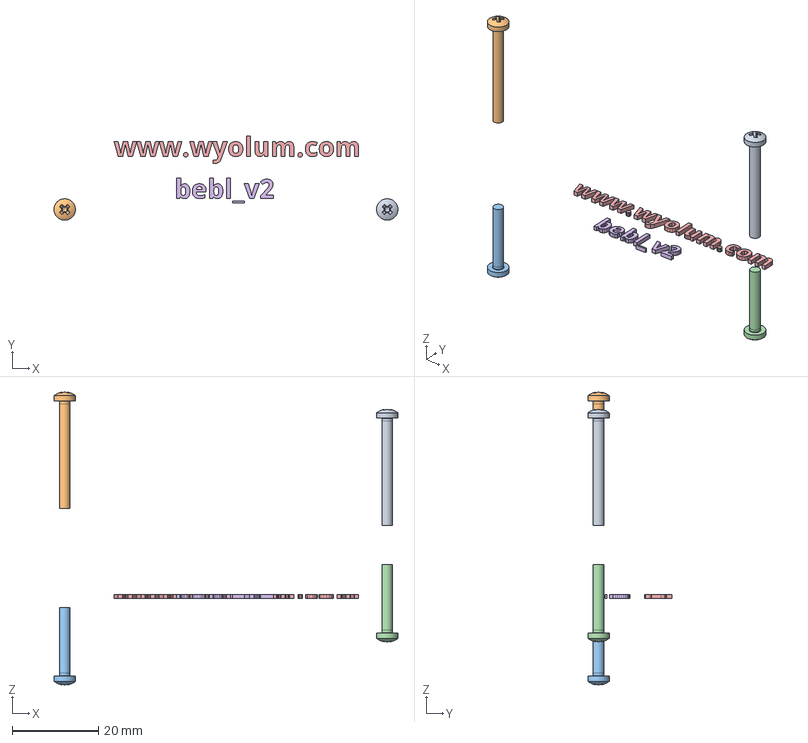
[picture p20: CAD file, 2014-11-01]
fabricate/bebl_v2_box02_XSection.fcstd
80.0 x 19.6 x 68.1 mm
ISO7045_M2_5x25_001
ISO7045_M2_5x25_003
ISO7045_M2_5x16_002
ISO7045_M2_5x16_003

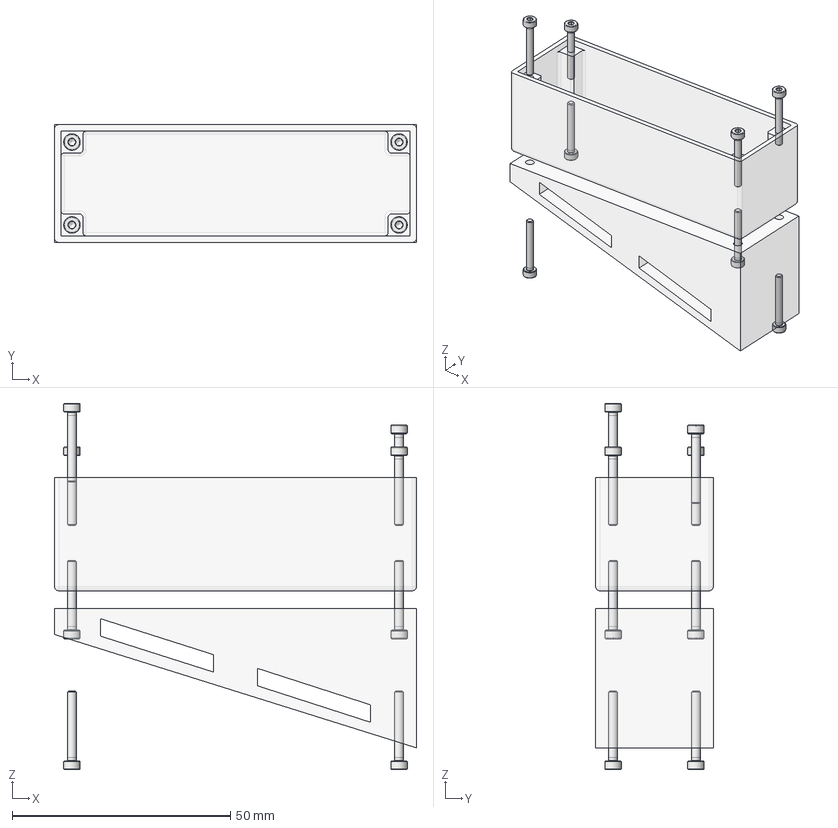
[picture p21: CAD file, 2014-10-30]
fabricate/bebl_v2_box01.fcstd
83.0 x 27.0 x 84.0 mm
ISO4762_M2x16_
ISO4762_M2x16_001
ISO4762_M2x16_002
ISO4762_M2x16_003
ISO4762_M2x16_004
ISO4762_M2x16_005
ISO4762_M2x16_006
ISO4762_M2x16_007

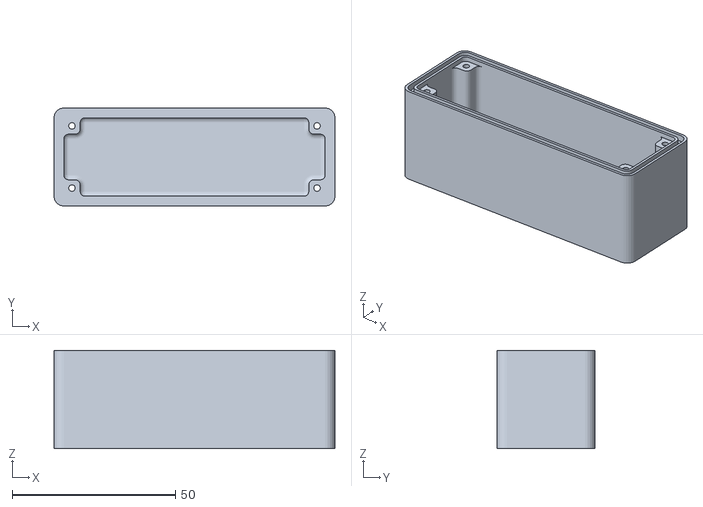
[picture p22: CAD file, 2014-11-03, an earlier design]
fabricate/old_archive/mainbox.stl
86.0 x 30.0 x 30.0

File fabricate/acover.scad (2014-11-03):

$fn=50;
mm = 1;
inch = 25.4 * mm;

SCREW_R = 2.6 * mm / 2.;
SCREW_Y_SEP = 19 * mm;
SCREW_Z_SEP = 75 * mm;
SCREW_OFF = 5.5 * mm;
LED_R = 5 * mm / 2;
LED_H = 10 * mm;

BORE_R = 5 * mm / 2;

Z = 86 * mm;
X = 10*mm;
Y = 27 * mm;
Y = 30 * mm;
T = 3 * mm;
FILLET_R = 3 * mm;

DEPTH = X - T;
POST_ANG = 18;


LED_OFF = 13 * mm;
LED_SEP = 10 * mm;
N_LED = 5;

module base(){
  difference(){
    cube([X, Y, Z]);
    
    // screw holes
    translate([-1, SCREW_OFF, SCREW_OFF])
      rotate(a=90, v=[0, 1, 0])cylinder(h=100*mm, r=SCREW_R);
    translate([-1, SCREW_OFF + SCREW_Y_SEP, SCREW_OFF])
      rotate(a=90, v=[0, 1, 0])cylinder(h=100*mm, r=SCREW_R);
    translate([-1, SCREW_OFF + SCREW_Y_SEP, SCREW_OFF + SCREW_Z_SEP])
      rotate(a=90, v=[0, 1, 0])cylinder(h=100*mm, r=SCREW_R);
    translate([-1, SCREW_OFF, SCREW_OFF + SCREW_Z_SEP])
      rotate(a=90, v=[0, 1, 0])cylinder(h=100*mm, r=SCREW_R);
    
    // counter bores
    translate([-1, SCREW_OFF, SCREW_OFF])
      rotate(a=90, v=[0, 1, 0])cylinder(h=X - 1*mm + 1, r=BORE_R);
    translate([-1, SCREW_OFF + SCREW_Y_SEP, SCREW_OFF])
      rotate(a=90, v=[0, 1, 0])cylinder(h=X - 1*mm + 1, r=BORE_R);
    translate([-1, SCREW_OFF + SCREW_Y_SEP, SCREW_OFF + SCREW_Z_SEP])
      rotate(a=90, v=[0, 1, 0])cylinder(h=X - 1*mm + 1, r=BORE_R);
    translate([-1, SCREW_OFF, SCREW_OFF + SCREW_Z_SEP])
      rotate(a=90, v=[0, 1, 0])cylinder(h=X - 1*mm + 1, r=BORE_R);
  }
}

module cover(){
  SCREW_PAD = 9 * mm;
  difference(){
    intersection(){
      base();
      // round edges
      translate([0, FILLET_R, FILLET_R])
	minkowski(){
	cube([X, Y - 2 * FILLET_R, Z - 2 * FILLET_R]);
	rotate(v=[0,1, 0], a=90)cylinder(r=FILLET_R,h=10);
      }
    }
    //hollow out
    translate([T, T, SCREW_PAD])cube([DEPTH + 1, Y - 2 * T, Z - 2 * SCREW_PAD]);
    translate([T, SCREW_PAD, T])cube([DEPTH + 1, Y - 2 * SCREW_PAD, Z - 2 * T]);
  }
}
difference(){
  cover();
  for(i = [0:N_LED-1]){
    translate([-1, Y/2, LED_OFF + i * LED_SEP])rotate(a=90, v=[0, 1, 0])cylinder(r=LED_R, h=LED_H);
  }
  translate([-1, Y/2, LED_OFF + (N_LED + 1) * LED_SEP])rotate(a=90, v=[0, 1, 0])cylinder(r=LED_R, h=LED_H);
}

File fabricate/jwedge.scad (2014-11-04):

$fn=50;
// rails

mm = 1;
inch = 25.4 * mm;

POST_R = 35 * mm / 2.;
SCREW_R = 2.6 * mm / 2.;
SCREW_Y_SEP = 19 * mm;
SCREW_Z_SEP = 75 * mm;
SCREW_OFF = 5.5 * mm;
BAND_W = 20 * mm; // for .75" strap
BAND_W = 1*inch + 1 * mm; // for 1" strap
BAND_T = 3 * mm;
BAND_OFF = 6 * mm;

BORE_R = 6 * mm / 2;

Z = 83 * mm;
Z = 86 * mm;
X0 = 25 * mm;
X1 = 26.5 * mm;
X = X0 + X1;
Y = 27 * mm;
Y = 30 * mm;
POST_ANG = 18;
FILLET_R = 3 * mm;

module jwedge(){
  intersection(){
    difference(){
      // main wedge
      difference(){
	cube([X, Y, Z]);
	rotate(a=POST_ANG, v=[0, 1, 0])
	  union(){
	  translate([-X, -1, 0]) cube([X, Y + 2, 2 * Z]);
	  translate([0, Y/2, 0]) cylinder(r=POST_R, h = 10 * Z + 2);
	}  
      }
      // screw holes
      translate([0, SCREW_OFF, SCREW_OFF])
	rotate(a=90, v=[0, 1, 0])cylinder(h=100*mm, r=SCREW_R);
      translate([0, SCREW_OFF + SCREW_Y_SEP, SCREW_OFF])
	rotate(a=90, v=[0, 1, 0])cylinder(h=100*mm, r=SCREW_R);
      translate([0, SCREW_OFF + SCREW_Y_SEP, SCREW_OFF + SCREW_Z_SEP])
	rotate(a=90, v=[0, 1, 0])cylinder(h=100*mm, r=SCREW_R);
      translate([0, SCREW_OFF, SCREW_OFF + SCREW_Z_SEP])
	rotate(a=90, v=[0, 1, 0])cylinder(h=100*mm, r=SCREW_R);
  
      // counter bores
      translate([0, SCREW_OFF, SCREW_OFF])
	rotate(a=90, v=[0, 1, 0])cylinder(h=X - 4*mm, r=BORE_R);
      translate([0, SCREW_OFF + SCREW_Y_SEP, SCREW_OFF])
	rotate(a=90, v=[0, 1, 0])cylinder(h=X - 4*mm, r=BORE_R);
      translate([0, SCREW_OFF + SCREW_Y_SEP, SCREW_OFF + SCREW_Z_SEP])
	rotate(a=90, v=[0, 1, 0])cylinder(h=X - 4*mm, r=BORE_R);
      translate([0, SCREW_OFF, SCREW_OFF + SCREW_Z_SEP])
	rotate(a=90, v=[0, 1, 0])cylinder(h=X - 4*mm, r=BORE_R);

      // BAND
      rotate(a=POST_ANG, v=[0, 1, 0])
	translate([0, Y/2, Z/3])
	difference(){
	cylinder(r=POST_R + BAND_OFF +  + BAND_T, h=BAND_W);
	translate([0, 0, -1])cylinder(r=POST_R + 6 * mm, h=BAND_W + 2);
    
      }
    }

    // round edges
    translate([0, FILLET_R, FILLET_R])
      minkowski(){
      cube([X, Y - 2 * FILLET_R, Z - 2 * FILLET_R]);
      rotate(v=[0,1, 0], a=90)cylinder(r=FILLET_R,h=10);
    }
  }
}
rotate(a=90, v=[0, 1, 0]) jwedge();

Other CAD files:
fabricate/old_archive/topcover.stl
fabricate/jcover.scad
fabricate/old_archive/jcover.scad

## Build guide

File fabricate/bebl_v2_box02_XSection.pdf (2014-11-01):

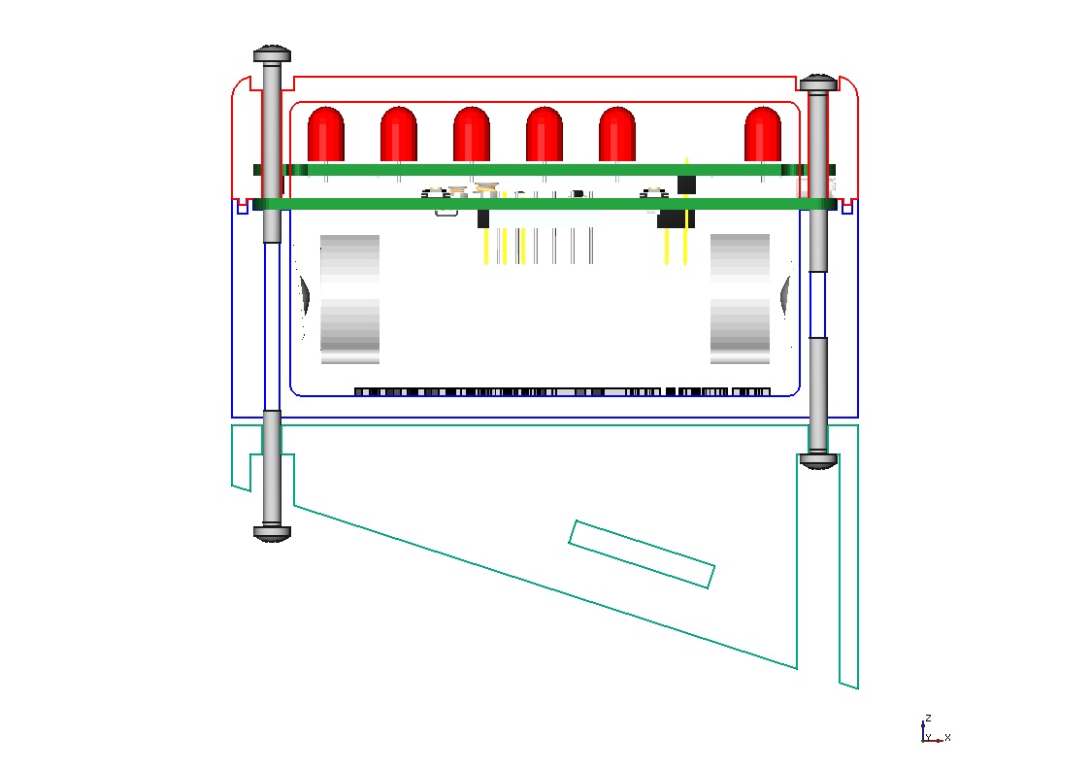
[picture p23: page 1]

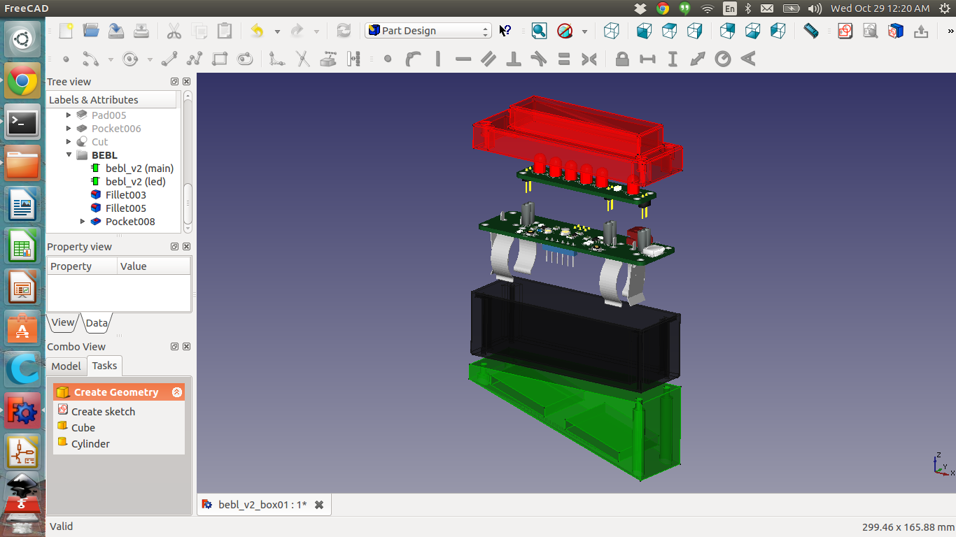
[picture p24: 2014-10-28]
fabricate/bebl_v2_box01.png

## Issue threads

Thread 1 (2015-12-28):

power supply buzzes (high freq)

wyojustin, 2015-12-28:
Switching power supply emits high frequency buzz when one LED is on, all the time when battery is low.

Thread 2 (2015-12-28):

Blinking LED stays lit

wyojustin, 2015-12-28:
A 1% duty cycle blinking LED indicates that the device is active.  Sometimes (even though the unit still functions) the LED gets stuck on.

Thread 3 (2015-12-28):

Device self resets on occasion.

wyojustin, 2015-12-28:
Not sure if this is a power issue.

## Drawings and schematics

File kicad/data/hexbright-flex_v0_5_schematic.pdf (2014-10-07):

# VOLTAGE REGULATOR

# USB TO SERIAL CONVERTER

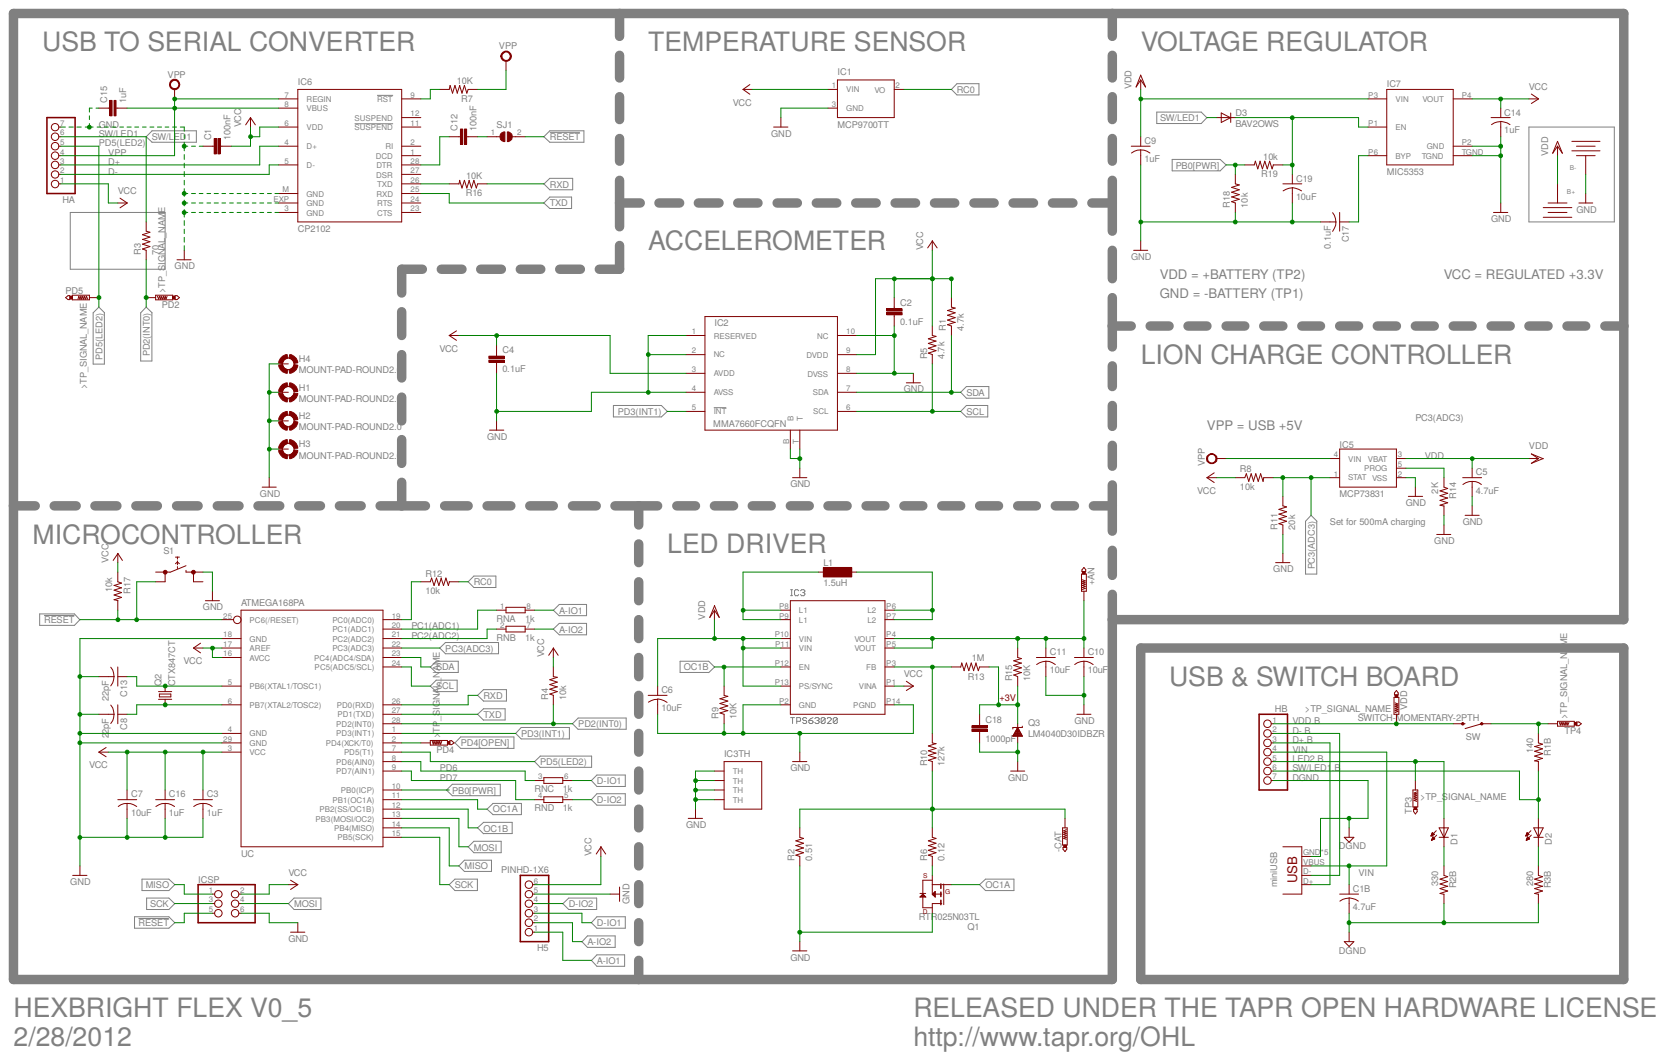
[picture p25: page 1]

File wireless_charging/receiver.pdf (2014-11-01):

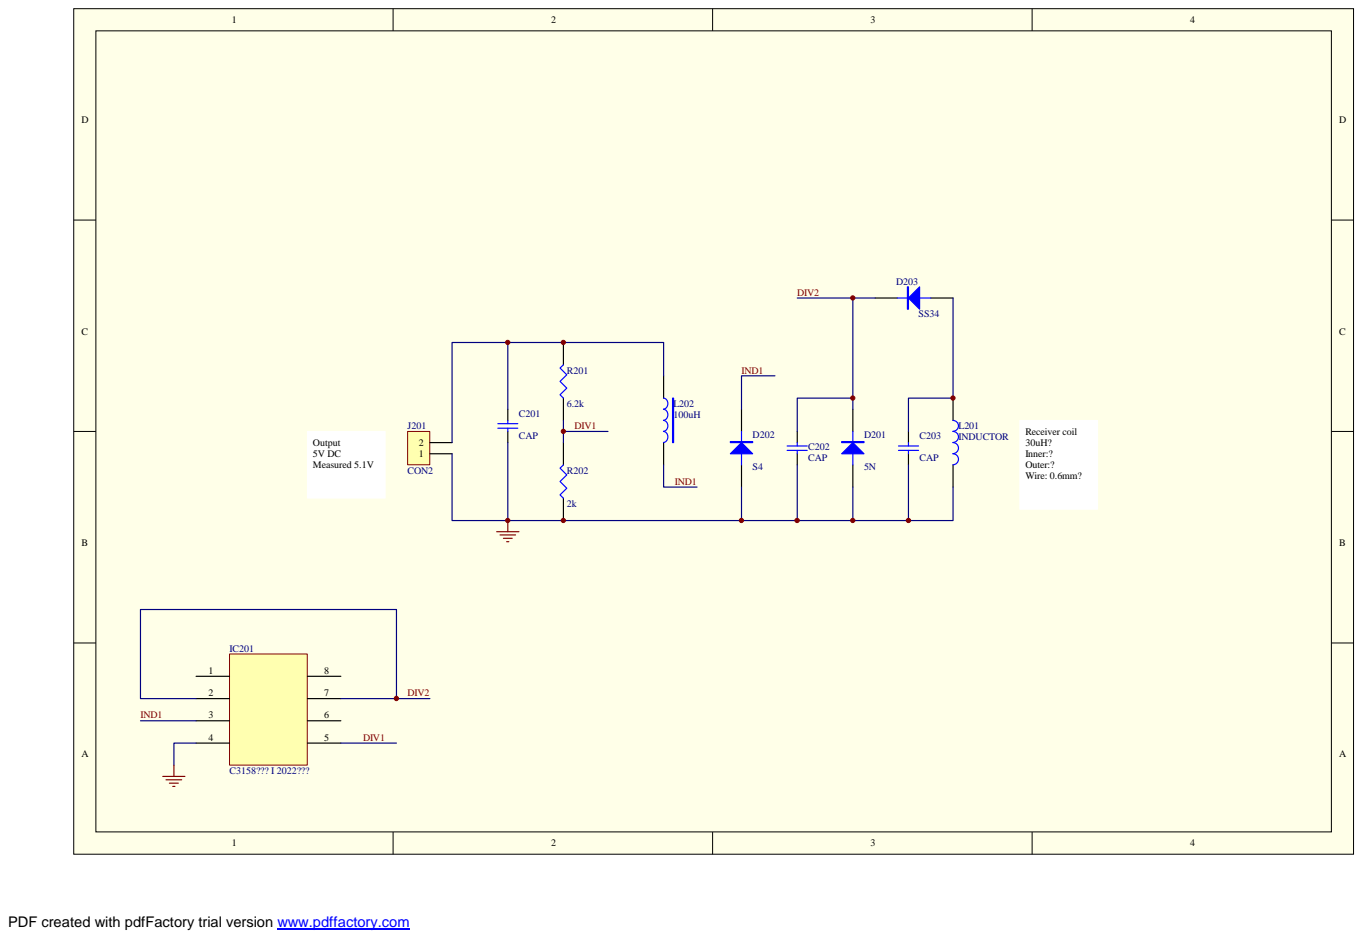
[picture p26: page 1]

PDF created with pdfFactory trial version www.pdffactory.com

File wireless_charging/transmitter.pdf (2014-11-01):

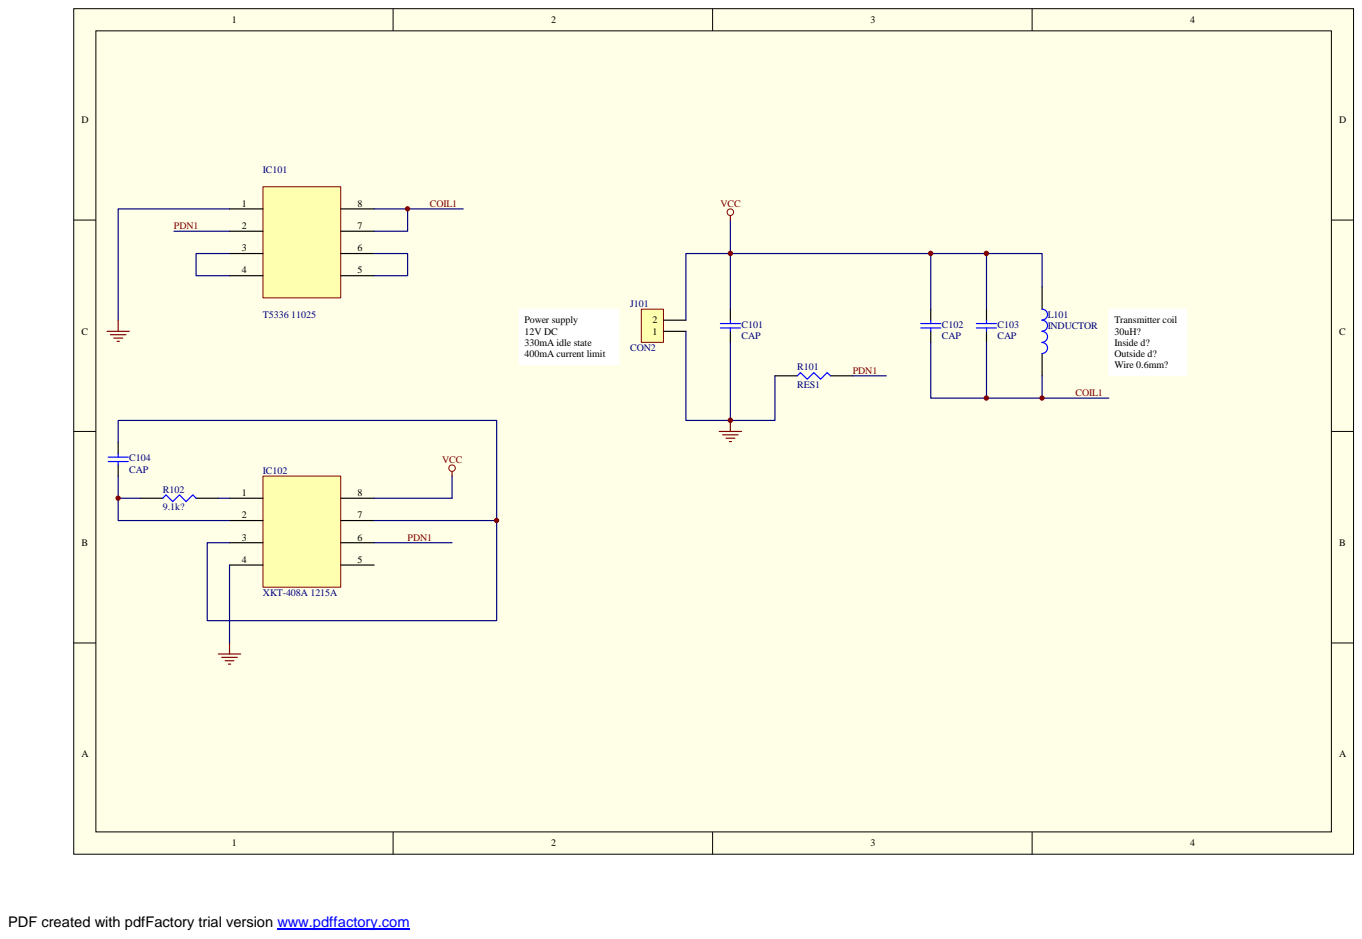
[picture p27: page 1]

PDF created with pdfFactory trial version www.pdffactory.com

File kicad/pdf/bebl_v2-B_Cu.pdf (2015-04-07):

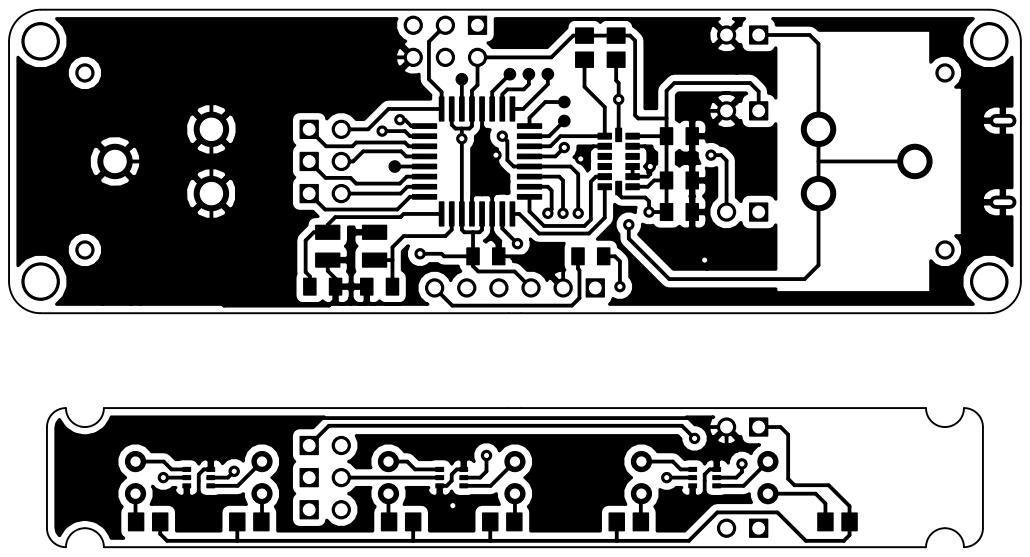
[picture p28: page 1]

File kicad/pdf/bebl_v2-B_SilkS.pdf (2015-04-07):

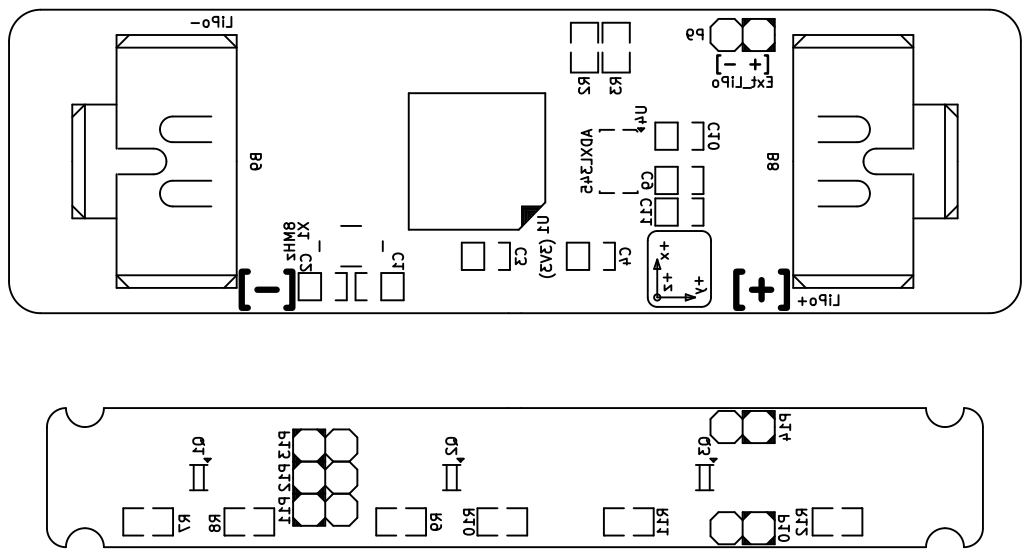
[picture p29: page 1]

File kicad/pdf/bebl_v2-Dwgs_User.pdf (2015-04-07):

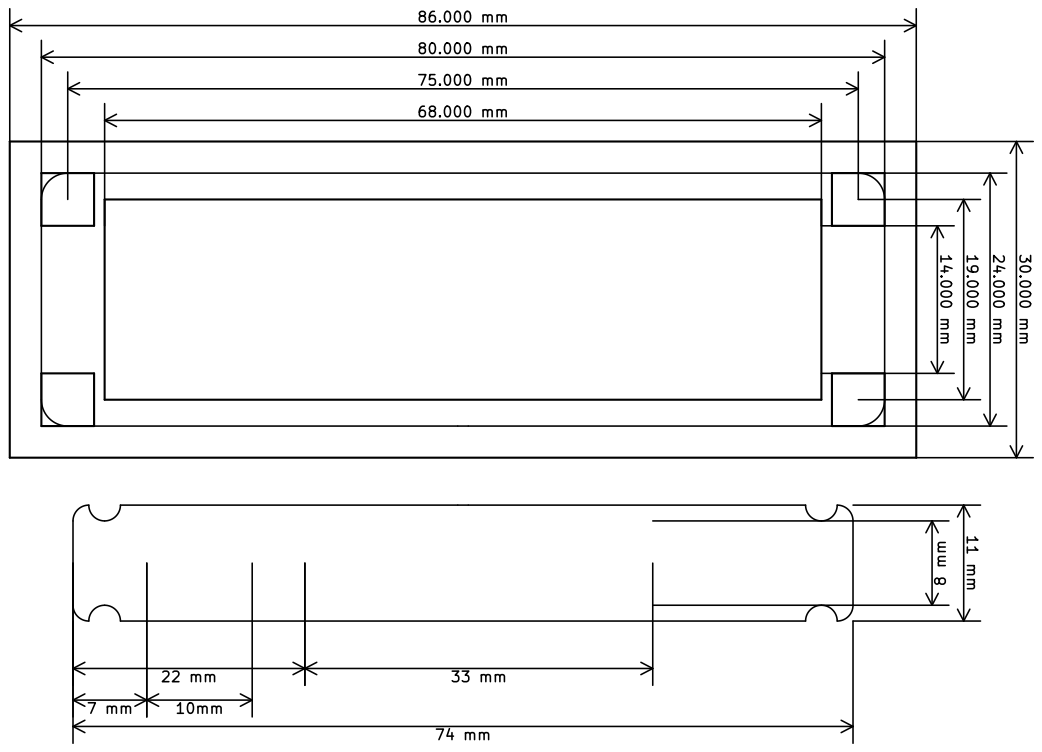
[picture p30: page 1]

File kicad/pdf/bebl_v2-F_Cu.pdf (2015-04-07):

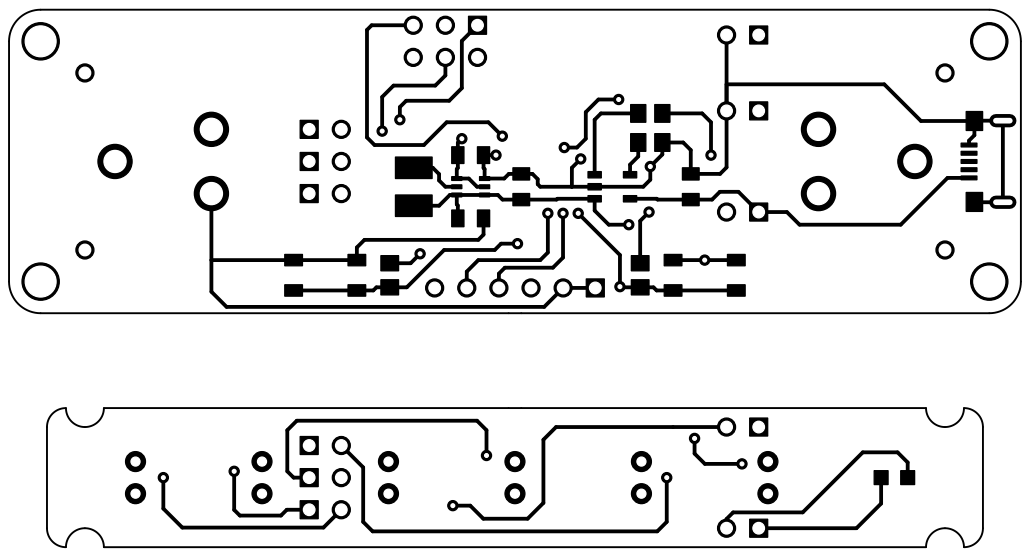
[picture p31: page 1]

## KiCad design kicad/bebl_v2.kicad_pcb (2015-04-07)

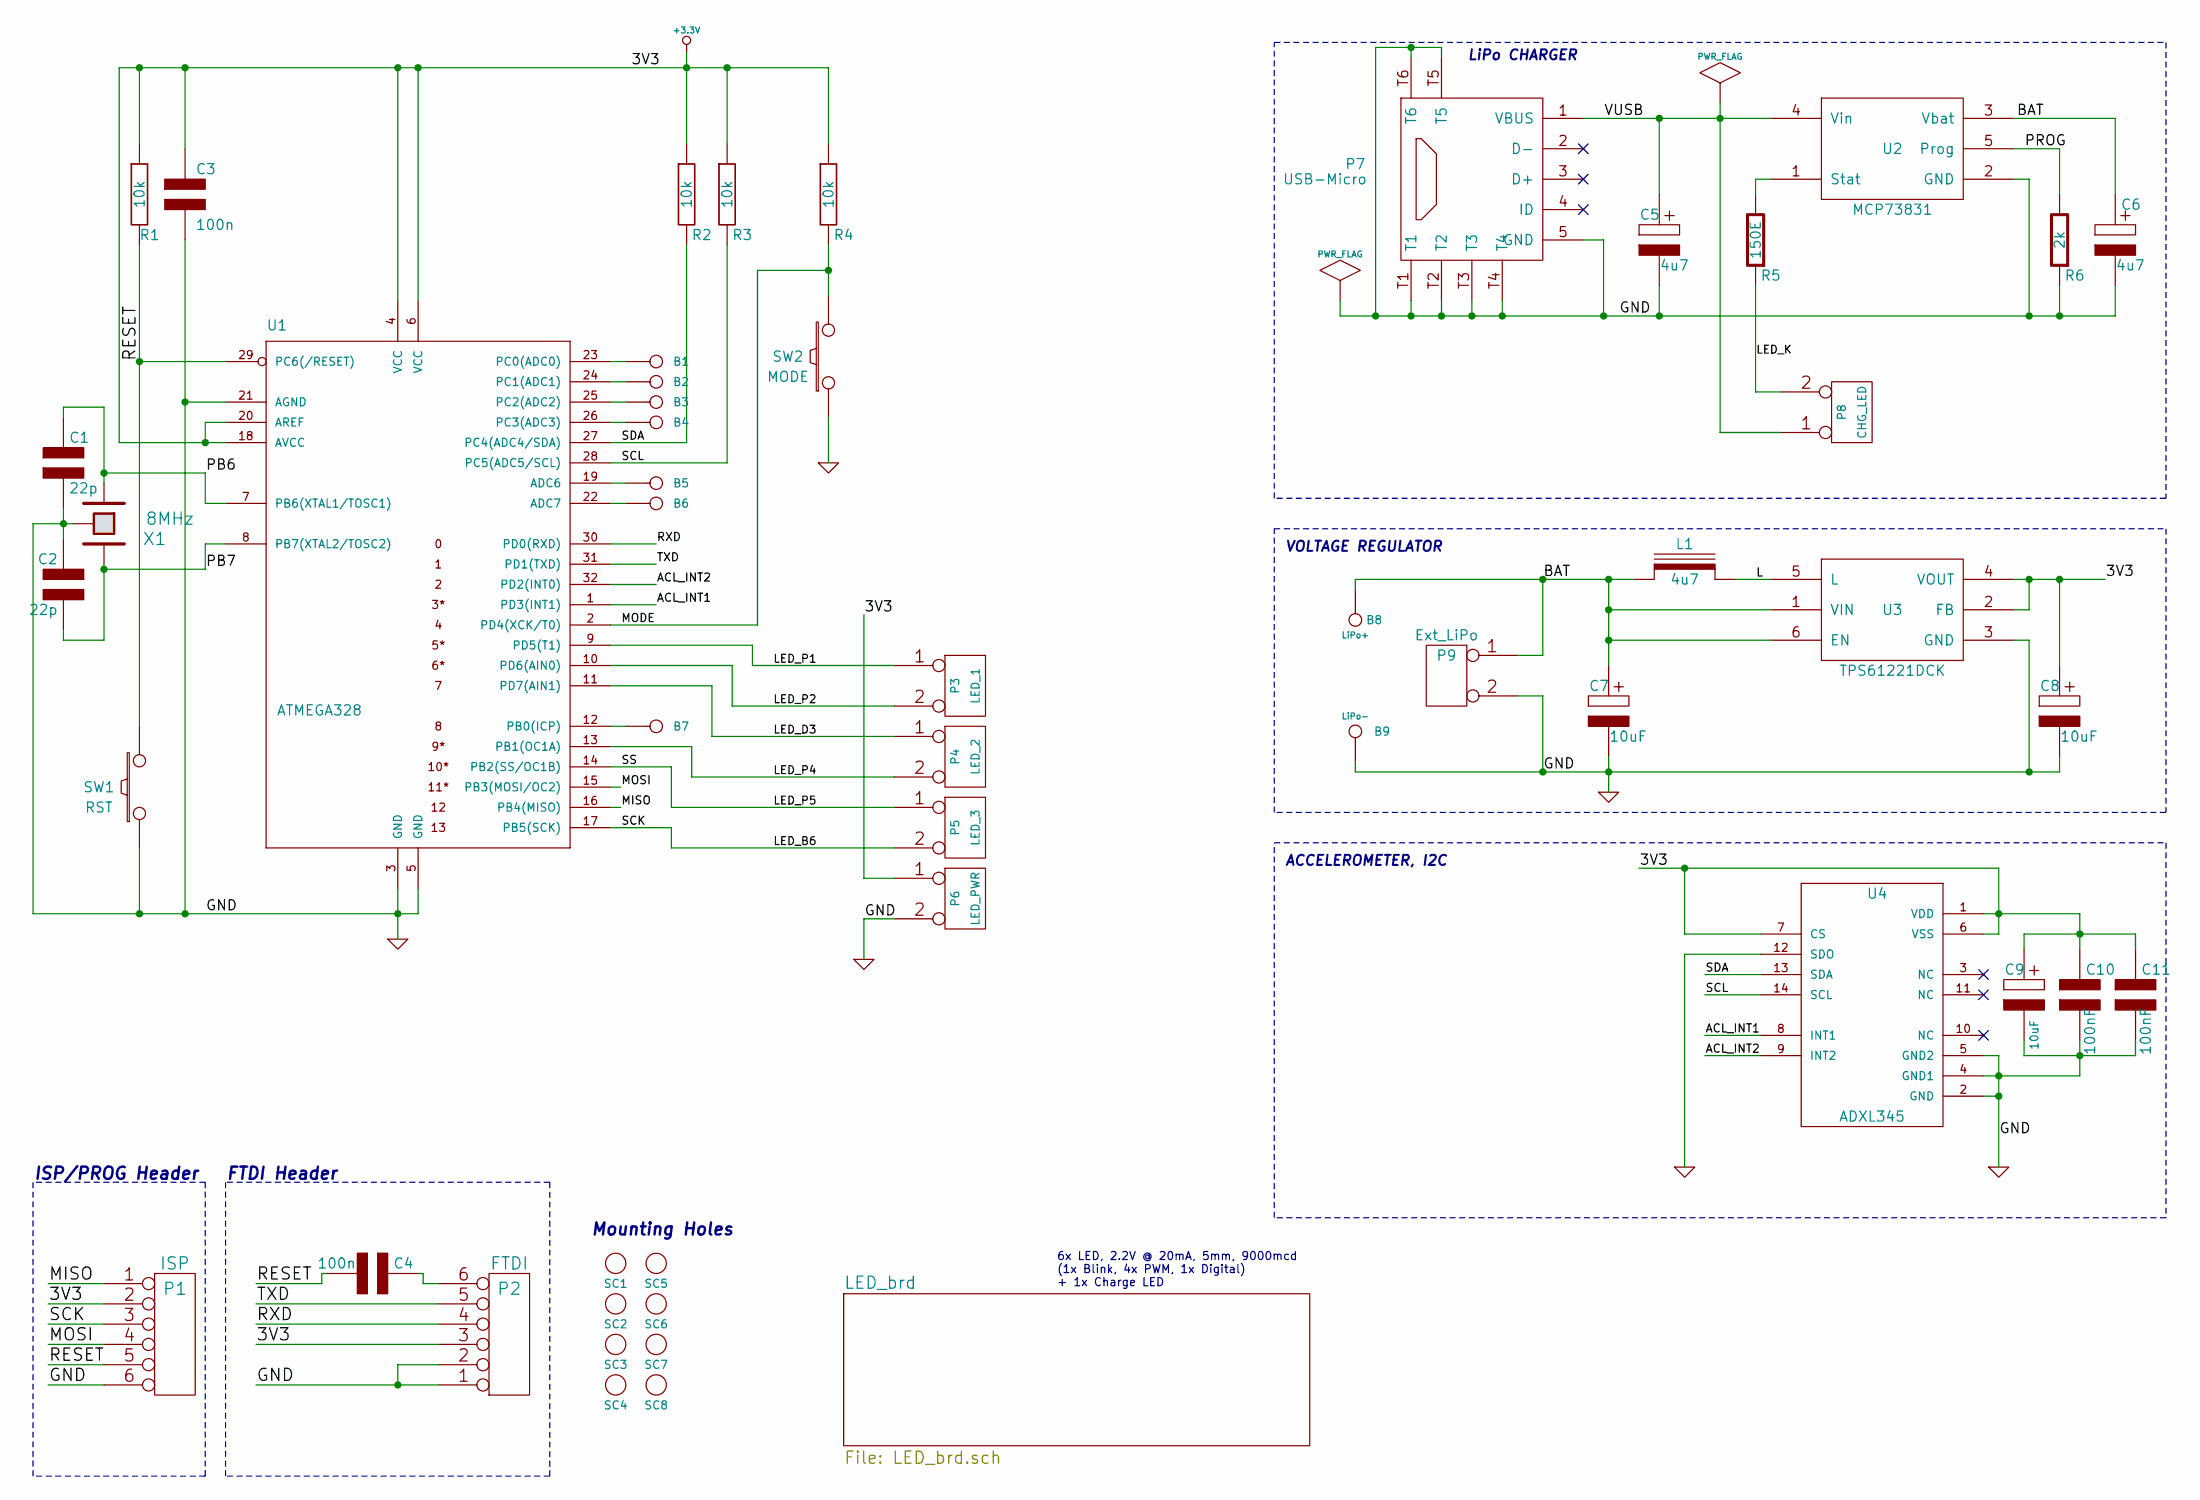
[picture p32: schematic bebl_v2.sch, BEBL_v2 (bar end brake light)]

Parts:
B1, B2, B3, B4, B5, B6, B7: I/O; breakout_smd
B8: LiPo+; batt_clip
B9: LiPo-; batt_clip
C1, C2: 22p; c_0805; Digikey 490-1734-1-ND
C3, C4: 100n; c_0805
C5, C6: 4u7; c_0805
C7, C8, C9: 10uF; c_0805
C10, C11: 100nF; c_0805
L1: 4u7; Inductor_LQH3NPN
P1: ISP; Header_3x2_ISP
P2: FTDI; PIN_ARRAY-6X1
P3: LED_1; pin_socket_2
P4: LED_2; pin_socket_2
P5: LED_3; pin_socket_2
P6: LED_PWR; pin_socket_2
P7: USB-Micro; USB_B_Micro_seeed
P8: CHG_LED; pin_socket_2
P9: Ext_LiPo; pin_socket_2
R1, R2, R3, R4: 10k; r_0805
R5: 150E; r_0805
R6: 2k; r_0805
SC1, SC2, SC3, SC4, SC5, SC6, SC7, SC8: SCREW; screw_3mm
SW1: RST; Switch_SMT
SW2: MODE; Switch_SMT
U1: ATMEGA328; TQFP32
U2: MCP73831; SOT23-5
U3: TPS61221DCK; SOT23-6_LDO
U4: ADXL345
X1: 8MHz; Xtal_SMD4

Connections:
+3.3V: C3.1, C8.1, C9.1, C10.1, C11.1, P1.2, P2.3, P6.1, R1.1, R2.1, R3.1, R4.1, U1.4 (VCC), U1.6 (VCC), U1.18 (AVCC), U1.20 (AREF), U3.2 (FB), U3.4 (VOUT), U4.1 (VDD), U4.6 (VSS), U4.7 (CS)
/ACL_INT1: U1.1 (PD3(INT1)), U4.8 (INT1)
/ACL_INT2: U1.32 (PD2(INT0)), U4.9 (INT2)
/BAT: B8.1, C6.1, C7.1, L1.1, P9.1, U2.3 (Vbat), U3.1 (VIN), U3.6 (EN)
/L: L1.2, U3.5 (L)
/LED_B6: P1.3, P5.2 (PM), U1.17 (PB5(SCK))
/LED_D3: P4.1, U1.11 (PD7(AIN1))
/LED_K: P8.2 (PM), R5.1
/LED_P1: P3.1, U1.9 (PD5(T1))
/LED_P2: P3.2 (PM), U1.10 (PD6(AIN0))
/LED_P4: P4.2 (PM), U1.13 (PB1(OC1A))
/LED_P5: P5.1, U1.14 (PB2(SS/OC1B))
/MISO: P1.1, U1.16 (PB4(MISO))
/MODE: R4.2, SW2.2, U1.2 (PD4(XCK/T0))
/MOSI: P1.4, U1.15 (PB3(MOSI/OC2))
/PB6: C1.1, U1.7 (PB6(XTAL1/TOSC1)), X1.1
/PB7: C2.1, U1.8 (PB7(XTAL2/TOSC2)), X1.2
/PROG: R6.2, U2.5 (Prog)
/RESET: C4.2, P1.5, R1.2, SW1.2, U1.29 (PC6(/RESET))
/RXD: P2.4, U1.30 (PD0(RXD))
/SCL: R3.2, U1.28 (PC5(ADC5/SCL)), U4.14 (SCL)
/SDA: R2.2, U1.27 (PC4(ADC4/SDA)), U4.13 (SDA)
/TXD: P2.5, U1.31 (PD1(TXD))
/VUSB: C5.1, P7.1 (VBUS), P8.1, U2.4 (Vin)
GND: B9.1, C1.2, C2.2, C3.2, C5.2, C6.2, C7.2, C8.2, C9.2, C10.2, C11.2, P1.6, P2.1, P2.2, P6.2 (PM), P7.5 (GND), P7.T1, P7.T2, P7.T3, P7.T4, P7.T5, P7.T6, P9.2 (PM), R6.1, SW1.1, SW2.1, U1.3 (GND), U1.5 (GND), U1.21 (AGND), U2.2 (GND), U3.3 (GND), U4.2 (GND), U4.4 (GND1), U4.5 (GND2), U4.12 (SDO), X1.3
unnamed: B1.1, U1.23 (PC0(ADC0))
unnamed: B2.1, U1.24 (PC1(ADC1))
unnamed: B3.1, U1.25 (PC2(ADC2))
unnamed: B4.1, U1.26 (PC3(ADC3))
unnamed: B5.1, U1.19 (ADC6)
unnamed: B6.1, U1.22 (ADC7)
unnamed: B7.1, U1.12 (PB0(ICP))
unnamed: C4.1, P2.6
unnamed: R5.2, U2.1 (Stat)

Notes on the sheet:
FTDI Header
ISP/PROG Header
Mounting Holes
ACCELEROMETER, I2C
VOLTAGE REGULATOR
LiPo CHARGER
6x LED, 2.2V @ 20mA, 5mm, 9000mcd (1x Blink, 4x PWM, 1x Digital) + 1x Charge LED

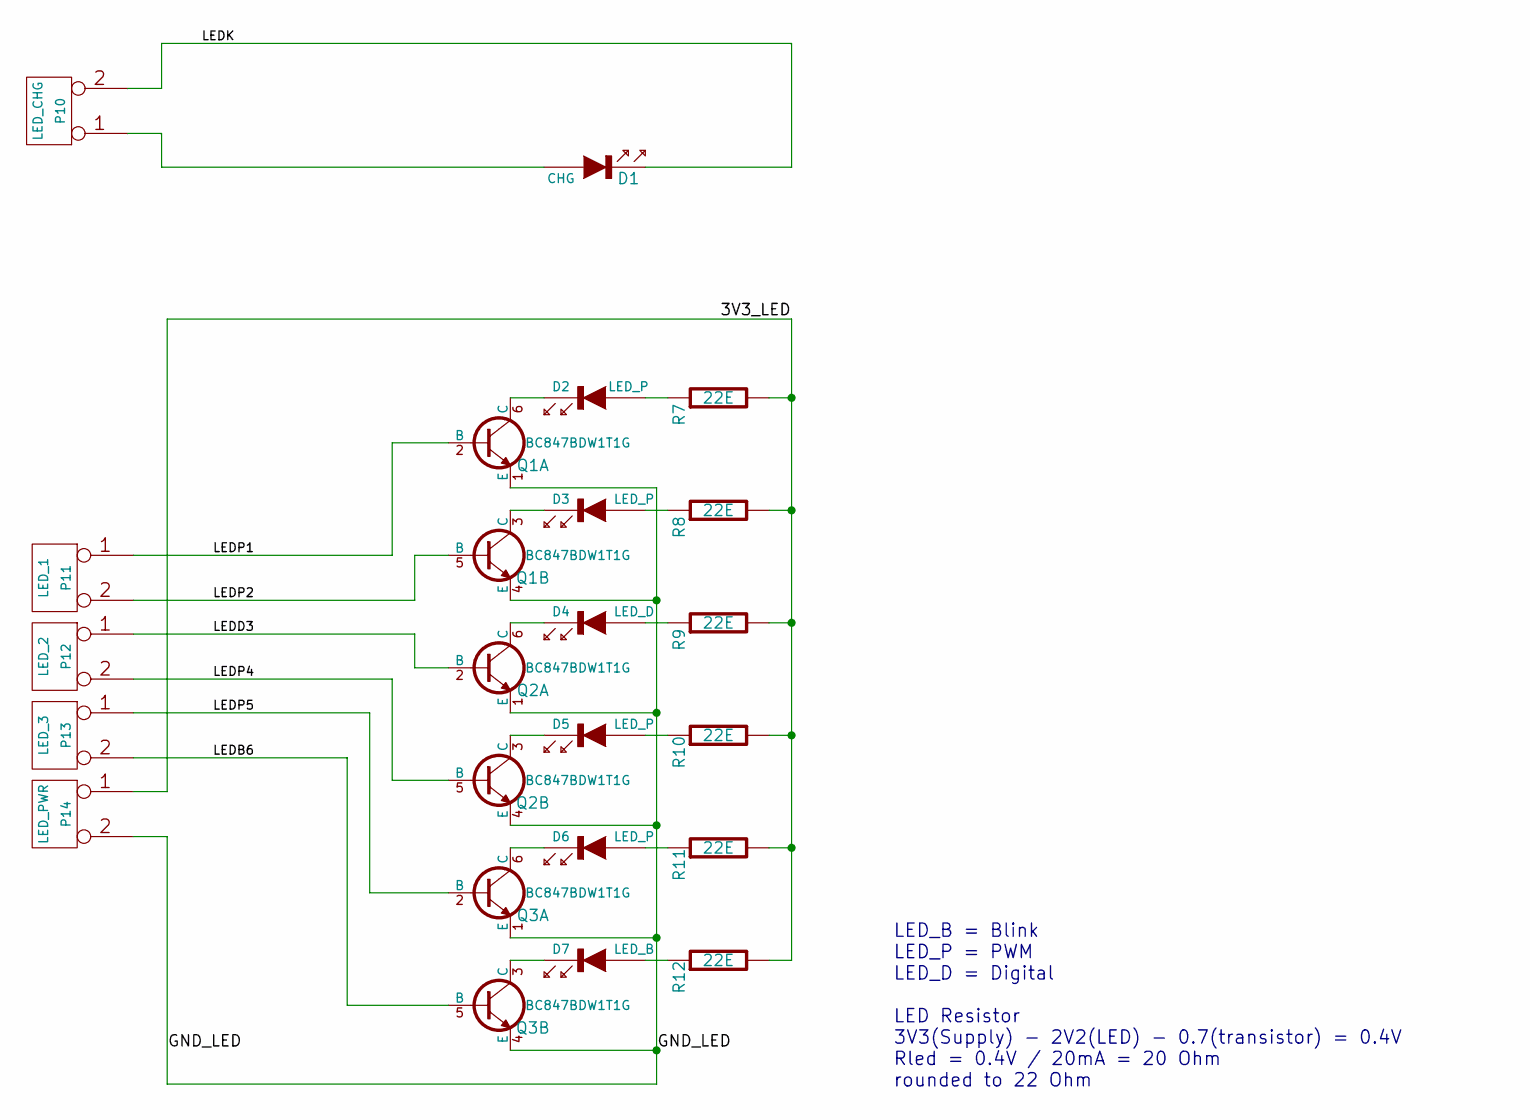
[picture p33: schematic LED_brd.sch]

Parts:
D1: CHG; LED-0805
D2, D3, D5, D6: LED_P; LED-5MM
D4: LED_D; LED-5MM
D7: LED_B; LED-5MM
P10: LED_CHG; pin_strip_2
P11: LED_1; pin_strip_2
P12: LED_2; pin_strip_2
P13: LED_3; pin_strip_2
P14: LED_PWR; pin_strip_2
Q1, Q2, Q3: BC847BDW1T1G; SOT363
R7, R8, R9, R10, R11, R12: 22E; r_0805

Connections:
/LED_brd/3V3_LED: P14.1, R7.2, R8.2, R9.2, R10.2, R11.2, R12.2
/LED_brd/GND_LED: P14.2 (PM), Q1.1 (E), Q1.4 (E), Q2.1 (E), Q2.4 (E), Q3.1 (E), Q3.4 (E)
/LED_brd/LEDB6: P13.2 (PM), Q3.5 (B)
/LED_brd/LEDD3: P12.1, Q2.2 (B)
/LED_brd/LEDK: D1.2 (K), P10.2 (PM)
/LED_brd/LEDP1: P11.1, Q1.2 (B)
/LED_brd/LEDP2: P11.2 (PM), Q1.5 (B)
/LED_brd/LEDP4: P12.2 (PM), Q2.5 (B)
/LED_brd/LEDP5: P13.1, Q3.2 (B)
unnamed: D1.1 (A), P10.1
unnamed: D2.1 (A), R7.1
unnamed: D2.2 (K), Q1.6 (C)
unnamed: D3.1 (A), R8.1
unnamed: D3.2 (K), Q1.3 (C)
unnamed: D4.1 (A), R9.1
unnamed: D4.2 (K), Q2.6 (C)
unnamed: D5.1 (A), R10.1
unnamed: D5.2 (K), Q2.3 (C)
unnamed: D6.1 (A), R11.1
unnamed: D6.2 (K), Q3.6 (C)
unnamed: D7.1 (A), R12.1
unnamed: D7.2 (K), Q3.3 (C)

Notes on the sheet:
LED_B = Blink LED_P = PWM LED_D = Digital LED Resistor 3V3(Supply) - 2V2(LED) - 0.7(transistor) = 0.4V Rled = 0.4V / 20mA = 20 Ohm rounded to 22 Ohm

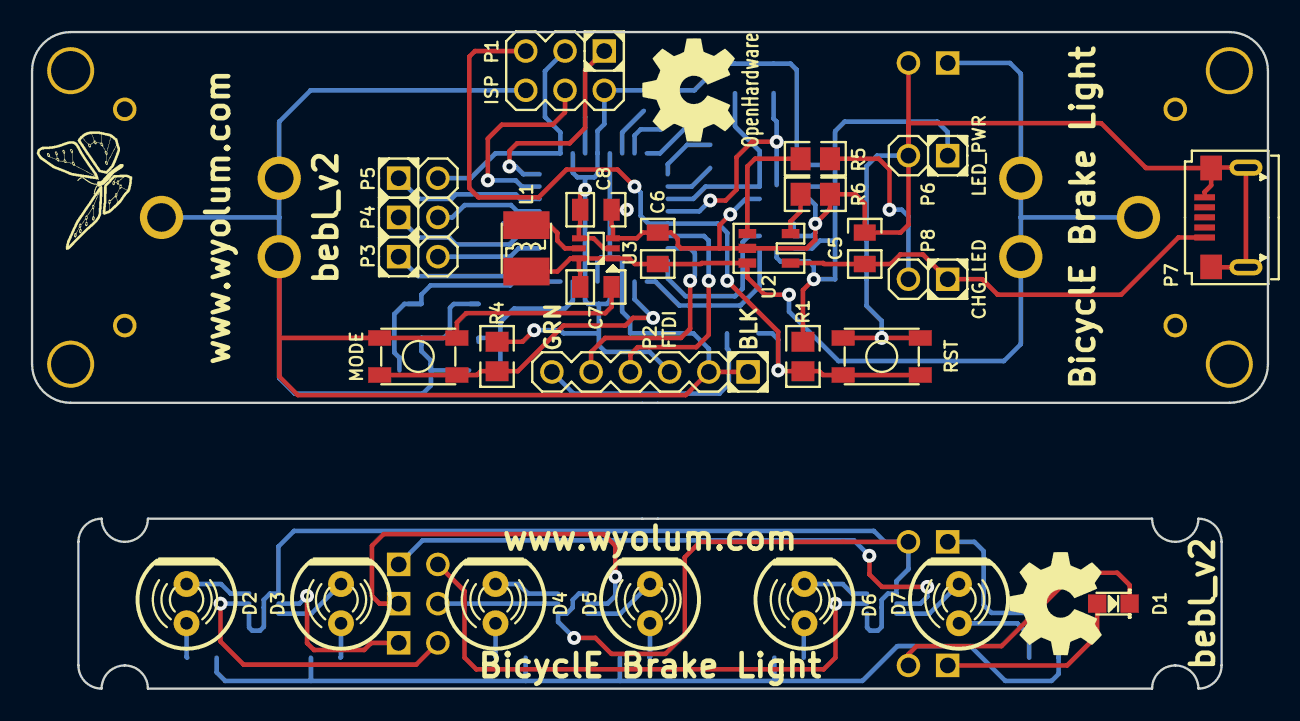
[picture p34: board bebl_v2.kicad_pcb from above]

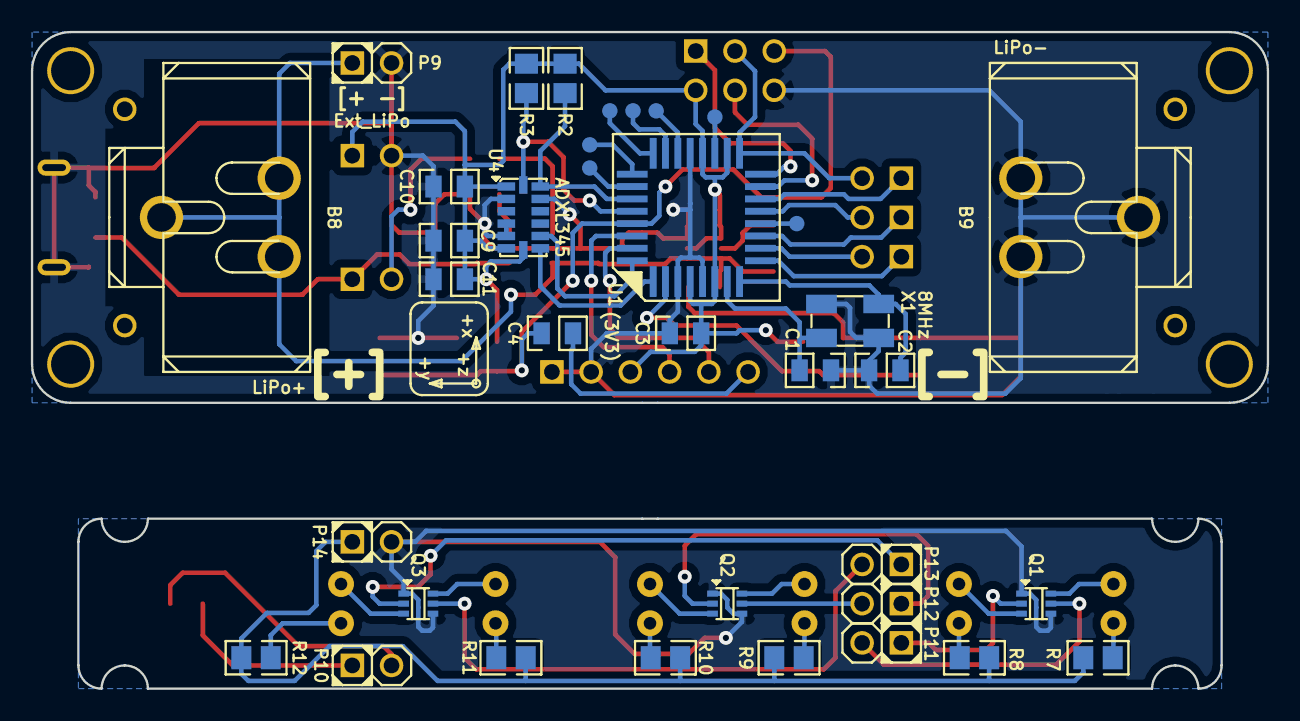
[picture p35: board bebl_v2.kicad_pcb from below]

Board: 2 copper layers, 80.0 x 42.5 mm, 73 parts (36 on the bottom side), 56 nets.

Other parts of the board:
G1: Logo-WL3

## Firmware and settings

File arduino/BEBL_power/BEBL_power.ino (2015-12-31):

/*
  Test out the LEDs and accel of BEBL
 */

#include "Wire.h"
#include "ADXL345.h"
#include <avr/sleep.h>

ADXL345 Accel;
const int LEDS[] = {5, 6, 7, 9, 10, 13}; // top to bottom
// const int LEDS[] = {7, 9, 6, 10, 5, 13}; // middle to outside

const int n_led = 6;

const int INTERRUPT_1 = 3;
const int INTERRUPT_2 = 2;
const int N_FILTER_CHANNEL = 3;
const int N_TAP = 3;
const int N_UP_TAP = 3;

// variable for filtered accel data
double cooked[N_FILTER_CHANNEL];

// variable for filtered up data
double up[N_FILTER_CHANNEL];
double back[N_FILTER_CHANNEL];
double braking = 0;
double braking_threshold = 0.05;

double in_data[N_TAP * N_FILTER_CHANNEL];
double out_data[N_TAP * N_FILTER_CHANNEL];
double up_in_data[N_UP_TAP * N_FILTER_CHANNEL];
double up_out_data[N_UP_TAP * N_FILTER_CHANNEL];

// 2.0 Hz
double ff_taps[] = { 0.00134871194836, 0.00269742389671, 0.00134871194836 };
double fb_taps[] = { 1.0, -1.89346414636, 0.898858994155 };
// 0.1 Hz
double up_ff_taps[] = { 3.54360709978e-06, 7.08721419957e-06, 3.54360709978e-06 };
double up_fb_taps[] = { 1.0, -1.99466855305, 0.994682727481 };
/*
// 1.0 Hz
double ff_taps[] = { 0.000346041337639, 0.000692082675278, 0.000346041337639 };
double fb_taps[] = { 1.0, -1.94669754076, 0.948081706107 };
// 0.05 Hz
double up_ff_taps[] = { 8.87081773651e-07, 1.7741635473e-06, 8.87081773651e-07 };
double up_fb_taps[] = { 1.0, -1.99733427181, 0.99733782014 };
*/

// apply IIR filter with coeff from _ff_taps and _fb_taps
// to each of N_FILTER_CHANNEL accel channels
double apply_filter(double _raw, double *_in_data, double *_out_data, int n_tap, double *_ff_taps, double *_fb_taps){
  double filtered = 0;
  byte i;

  // shift taps
  for(i = n_tap - 1; i > 0; i--){
    _in_data[i] = _in_data[i - 1];
  }
  _in_data[0] = _raw;

  // out = ibuff . b - obuff . a
  for(i = 0; i < n_tap; i++){
    filtered += _in_data[i] * _ff_taps[i];
  }
  for(i = 0; i < n_tap - 1; i++){
    filtered -= _out_data[i] * _fb_taps[i + 1];
  }
  // shift taps
  for(i = n_tap - 2; i > 0; i--){
    _out_data[i] = _out_data[i - 1];
  }
  _out_data[i] = filtered;

  return filtered;
}
  
// get raw data form a2d converters
// called by get_cooked
void get_acc_data(double *acc_data){
  Accel.get_Gxyz(acc_data);
}

double dot3(double *v, double* w){
  double out = 0;
  for(int i=0; i<3; i++){
    out += v[i] * w[i];
  }
  return out;
}

double norm(double *v3){
  return sqrt(dot3(v3, v3));
}

void normalize(double *v3){
  double n = norm(v3);
  for(int i=0; i < 3; i++){
    v3[i] /= n;
  }
}

// make call to get_acc_data() and apply IIR filter
void get_cooked(){
  int i, j;
  double acc_data[N_FILTER_CHANNEL];
  
  get_acc_data(acc_data);
  for(i = 0; i < N_FILTER_CHANNEL; i++){
    cooked[i] = apply_filter(acc_data[i], in_data + i * N_TAP, out_data + i * N_TAP, N_TAP, ff_taps, fb_taps);
    up[i] = apply_filter(acc_data[i], up_in_data + i * N_UP_TAP, up_out_data + i * N_UP_TAP, N_UP_TAP, up_ff_taps, up_fb_taps);
  }
  normalize(up);
  back[0] = up[2] * up[0];
  back[1] = up[2] * up[1];
  back[2] = -1 + up[2] * up[2];
  normalize(back);
  braking = dot3(cooked, back);
}

void setup(){
  Serial.begin(115200);
  Serial.println("Buy Open Hardware and own your future!");

  pinMode(INTERRUPT_1, INPUT_PULLUP);
  pinMode(INTERRUPT_2, INPUT_PULLUP);
  
  for(int i=0; i<n_led; i++){
    pinMode(LEDS[i], OUTPUT);
  }

  // configure accel bandwidth (Hz)
  Accel.set_bw(ADXL345_BW_25); // 3 6 12 25 50 100 200 400 800 1600
  // turn off all interrupts while we configure as per datasheet
  for(int bit_i=0; bit_i < 8; bit_i++){
    Accel.setInterrupt(bit_i, 0);
  }
  

  // set up taps
  Accel.setTapThreshold(0x48);
  Accel.setTapDuration(0x1F);
  Accel.setDoubleTapLatency(0x10);
  Accel.setDoubleTapWindow(0xFF);

  // turn on interrupts
  Accel.setTapDetectionOnX(true);
  Accel.setTapDetectionOnY(true);
  Accel.setTapDetectionOnZ(true);
  Accel.setSuppressBit(true);
  Accel.setTimeInactivity(10);
  Accel.setInactivityThreshold(0X10);
  Accel.setInactivityAc(true);
  Accel.setActivityThreshold(0x1F);
  Accel.setActivityX(true);
  Accel.setActivityY(true);
  Accel.setActivityZ(true);
  Accel.setActivityAc(true);

  // taps go to interrupt 0
  Accel.setInterruptMapping(ADXL345_INT_SINGLE_TAP_BIT, 0);
  Accel.setInterruptMapping(ADXL345_INT_DOUBLE_TAP_BIT, 0);

  // activity goes to interrupt 1
  Accel.setInterruptMapping(ADXL345_INT_INACTIVITY_BIT, 0);
  Accel.setInterruptMapping(ADXL345_INT_ACTIVITY_BIT, 0);

  // enable interrupts
  Accel.setInterrupt(ADXL345_INT_DOUBLE_TAP_BIT, 1);
  Accel.setInterrupt(ADXL345_INT_SINGLE_TAP_BIT, 1);
  Accel.setInterrupt(ADXL345_INT_ACTIVITY_BIT, 1);
  // I don't think we want an inactivity interrupt, but can still set thresholds to set power low
  Accel.setInterrupt(ADXL345_INT_INACTIVITY_BIT, 1);

  Accel.setInterruptLevelBit(true); // going low on interrupt 


  // turn on sampling
  Accel.powerOn();
    // attach interrupts
  attachInterrupt(1, interrupt_handler1, LOW); //tap interrupt
  //attachInterrupt(digitalPinToInterrupt(INTERRUPT_2), interrupt_handler1, FALLING);
  // saturate filter memory with current value.  It takes a while for IIR filter to saturate
  for(int i=0; i<200; i++){
    get_cooked();
  }
  // flash leds in sequence with a delay of 10 ms
  sweep(100);
}

// if true, then there is an event that has not yet been handled.
// one bool for each intertupt pin
volatile bool event_pending[2];

void interrupt_handler1(){
  sleep_disable(); //important or we will never wake.
  detachInterrupt(1);
  event_pending[1] = true;
}
void interrupt_handler0(){
  event_pending[0] = true;
}

// flash leds in sequence back and forth
void sweep(int d){
  int i;
  for(i=0; i<n_led; i++){
    digitalWrite(LEDS[i], HIGH);
    delay(d);
    digitalWrite(LEDS[i], LOW);
  }
  for(i=0; i<n_led; i++){
    digitalWrite(LEDS[n_led - i - 1], HIGH);
    delay(d);
    digitalWrite(LEDS[n_led - i - 1], LOW);
  }
}

// LED toggle states
bool bool0, bool1;
unsigned long acc_last_activity_ms = 0;
bool is_awake = true;

const unsigned long MILLIS = 1;
const unsigned long SECONDS = 1000 * MILLIS;
const unsigned long MINUTES = 60 * SECONDS;
const unsigned long ATTENTION_SPAN = 5 * SECONDS;
const double ACC_ACTIVITY_THRESH = .1;
// loop() counter
int count = 0;
int last_ms = 0;

const int sample_period_ms = 12;
int next_sample_time_ms = 0;

double last_acc_data[3];
void loop(){
  byte source =0;
  if(event_pending[0] || event_pending[1]){
      // this also clears the interrupt on the accel
      source = Accel.getInterruptSource();
      acc_last_activity_ms = millis();
      }
  if(event_pending[0] && event_pending[1]){
    Serial.println("\nBOTH");
    Serial.println(count);
  }
  if(event_pending[1]){
    Serial.println(source, BIN);
    Serial.println(" event1");
    event_pending[1] = false;
    if (source & 1<<ADXL345_INT_SINGLE_TAP_BIT)
      Serial.println("Single Tap");
    if (source & 1<<ADXL345_INT_DOUBLE_TAP_BIT)
      Serial.println("Double Tap");
    if (source & 1<<ADXL345_INT_ACTIVITY_BIT)
      Serial.println("Activity");
    if (source & 1<<ADXL345_INT_INACTIVITY_BIT)
      Serial.println("InActivity");        
    
    //make sure the interrupt is HIGH again
    while(!digitalRead(INTERRUPT_2));
    //reattach the interrupt
    attachInterrupt(1, interrupt_handler1, LOW);
  }
  if(event_pending[0]){
    Serial.println(source, BIN);
    Serial.println(" event0");
    event_pending[0] = false;
  }
  int i;
  double acc_data[3], acc_diff;
  
  int now_ms = millis();
  if(is_awake){
    if(now_ms > next_sample_time_ms){
      count++;
      get_cooked();
      if(count % 100 < 1){
	digitalWrite(LEDS[0], HIGH);
      }
      else{
	digitalWrite(LEDS[0], LOW);
      }
      next_sample_time_ms += sample_period_ms;
      if(count% 100 == 0){
	Serial.println(now_ms - last_ms);
	last_ms = now_ms;
      }
    }
    // Serial.println(braking);
    if(braking > braking_threshold){
      acc_last_activity_ms = millis();
      for(i=1; i<n_led; i++){
	digitalWrite(LEDS[i], HIGH);
      }
    }
    else{
      for(i=1; i<n_led; i++){
	digitalWrite(LEDS[i], LOW);
      }
    }
    if(millis() - acc_last_activity_ms > ATTENTION_SPAN){
      go_to_sleep();
    }
  }
}

void go_to_sleep(){
  for(int i=0; i < n_led; i++){
    digitalWrite(LEDS[i], LOW);
  }
  is_awake = false;
  Serial.println("SLEEP!");
  sleep_enable();
  attachInterrupt(1, interrupt_handler1, LOW);

  set_sleep_mode(SLEEP_MODE_PWR_DOWN);
  cli();
  sleep_bod_disable();
  sei();
  sleep_cpu();
  /* wake up here */
  sleep_disable();
  next_sample_time_ms = millis();
  is_awake = true;
  Serial.println("AWAKE!");
}

void wake_up(){

}

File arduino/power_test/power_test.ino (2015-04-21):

/*
  Test out the LEDs and accel of BEBL
 */

#include "Wire.h"
#include "ADXL345.h"
//KGO_BEGIN
//atmega sleep mode includes
#include <avr/sleep.h> //Needed for sleep_mode
#include <avr/power.h> //Needed for powering down perihperals such as the ADC/TWI and Timers
long lastWakeTime;
// how many millis before we go to sleep
#define INACTIVITY 3000
//KGO_END

ADXL345 Accel;
int LEDS[] = {5, 6, 7, 9, 10, 13};
int n_led = 6;

int INTERRUPT_1 = 2;
int INTERRUPT_2 = 3;

bool event_pending[2];
void AccelSetup();
void setup(){
  pinMode(INTERRUPT_1, INPUT);
  pinMode(INTERRUPT_2, INPUT);
  
  Serial.begin(115200);
  Serial.println("Buy Open Hardware and own your future!");
  for(int i=0; i<n_led; i++){
    pinMode(LEDS[i], OUTPUT);
  }
  AccelSetup();
  sweep(10);
  lastWakeTime = millis();
}

// this also gets called when waking from sleep. we should probably figure out
// what's needed only on wakeup
void AccelSetup(){
  
  // configure accel
  Accel.set_bw(ADXL345_BW_3); // 3 6 12 25 50 100 200 400 800 1600
  //Accel.set_bw(ADXL345_BW_1600);
  Accel.setInactivityAc(true);

  // turn off interrupts
  for(int bit_i=0; bit_i < 8; bit_i++){
    Accel.setInterrupt(bit_i, 0);
  }

  Accel.setTapThreshold(0x28);
  Serial.println(Accel.getTapThreshold(), HEX);
  Accel.setTapDuration(0xFF);
  Serial.println(Accel.getTapDuration(), HEX);
  Accel.setDoubleTapLatency(0x50);
  Serial.println(Accel.getDoubleTapLatency(), HEX);
  Accel.setDoubleTapWindow(0xFF);
  Serial.println(Accel.getDoubleTapWindow(), HEX);

  // turn on interrupts
  Accel.setTapDetectionOnX(true);
  Accel.setTapDetectionOnY(true);
  Accel.setTapDetectionOnZ(true);
  Accel.setSuppressBit(true);
  Accel.setTimeInactivity(10);
  Accel.setInactivityThreshold(0X02);
  Accel.setActivityX(true);
  Accel.setActivityY(true);
  Accel.setActivityZ(true);
  Accel.setActivityAc(true);

  Accel.setInterruptLevelBit(false); // Rising edge on interrupt

// This sets the ADX345 to send taps to INT1 pin which is connected to Pin 3 on arduino
  Accel.setInterruptMapping(ADXL345_INT_SINGLE_TAP_BIT, 0);
  Accel.setInterruptMapping(ADXL345_INT_DOUBLE_TAP_BIT, 0);
  
// This sets the ADX345 to send inactivity to INT2 pin which is connected to Pin 2 on arduino
  Accel.setInterruptMapping(ADXL345_INT_INACTIVITY_BIT, 1);
  Accel.setInterruptMapping(ADXL345_INT_ACTIVITY_BIT, 1);
  

  Accel.setInterrupt(ADXL345_INT_DOUBLE_TAP_BIT, 1);
  Accel.setInterrupt(ADXL345_INT_SINGLE_TAP_BIT, 1);
  
  Accel.setInterrupt(ADXL345_INT_ACTIVITY_BIT, 1);
  Accel.setInterrupt(ADXL345_INT_INACTIVITY_BIT, 1);
 

  attachInterrupt(0, interrupt_handler0, RISING);
  attachInterrupt(1, interrupt_handler1, RISING);
  Accel.powerOn();
}
void interrupt_handler0(){
  event_pending[0] = true;
}
void interrupt_handler1(){
  event_pending[1] = true;
}

void sweep(int d){
  int i;
  for(i=0; i<n_led; i++){
    digitalWrite(LEDS[i], HIGH);
    delay(d);
    digitalWrite(LEDS[i], LOW);
  }
  for(i=0; i<n_led; i++){
    digitalWrite(LEDS[n_led - i - 1], HIGH);
    delay(d);
    digitalWrite(LEDS[n_led - i - 1], LOW);
  }
}

int led;
bool bool0, bool1;
int count = 0;
void loop(){
  count++;
  byte tmpbyte;
  byte source = Accel.getInterruptSource();
  if(event_pending[0] && event_pending[1]){
    Serial.println("\nBOTH");
    Serial.println(count);
  }
  if(event_pending[0]){
    Serial.println(source, BIN);
    Serial.println(" event0");
    event_pending[0] = false;
    bool0 = !bool0;
      // first turn off all the LEDs
    for(int i=0; i<n_led - 1; i++){
      digitalWrite(LEDS[i],HIGH);
      delay(200);
      digitalWrite(LEDS[i], LOW);
      delay(100);
    }
    goToSleep();
  }
  if(event_pending[1]){
    Serial.println(source, BIN);
    Serial.println(" event1");
    event_pending[1] = false;
    bool1 = !bool1;
    digitalWrite(LEDS[n_led-1], bool1);
  }

  return;
  int i;
  double acc_data[3];
  Accel.get_Gxyz(acc_data);

  if(Accel.status){
    float length = 0.;
    for(i = 0; i < 3; i++){
      length += (float)acc_data[i] * (float)acc_data[i];
      Serial.print(acc_data[i]);
      Serial.print(" ");
    }
    length = sqrt(length);
    Serial.print(length);
    Serial.println("");
    
    /*
    if(acc_data[2] < 0){
      int led_i = (int)(-n_led * acc_data[2]);
      for(i=0; i<n_led; i++){
	digitalWrite(LEDS[i], LOW);
      }
      digitalWrite(LEDS[led_i], HIGH);
    }
    */
    for(i=1; i<n_led - 1; i++){
      if(acc_data[2] < -.1 * (i)){
	digitalWrite(LEDS[i], HIGH);
      }
      else{
	digitalWrite(LEDS[i], LOW);
      }
    }
  }
  else{
    Serial.print("ERROR: ADXL345 data read error:");
    Serial.println(Accel.error_code);
    digitalWrite(7, HIGH);
    while(1) delay(1000);
  }
}
// KGO_BEGIN
// Atmega sleep/wake routines

void goToSleep(){ 
  Serial.println("Going to Sleep");
  detachInterrupt(0);// we don't want to keep getting interrupted when waking

  delay(100);
  set_sleep_mode(SLEEP_MODE_PWR_DOWN);
  sleep_enable();
  //attachInterrupt(0,wake,RISING); // pin 2 intterupt Inactivity
  attachInterrupt(1,wake,RISING);// pin 3 interrupt  tap
  power_twi_disable();
//  power_spi_disable();
  power_usart0_disable();
//  power_timer0_disable(); //Needed for delay_ms and apparently for pin interrupts
  power_timer1_disable();
  power_timer2_disable(); 
  sleep_mode(); // this immediately goes to sleep
  // and when we wake up, we will execute this
  detachInterrupt(0);// we don't want to keep getting interrupted when waking
  detachInterrupt(1);

  sleep_disable();
  power_twi_enable();
//  power_spi_enable();
  power_usart0_enable();
//  power_timer0_enable(); //Needed for delay_ms
  power_timer1_enable();
  power_timer2_enable(); 
  Serial.println("waking up");
  AccelSetup();

  //Serial.println("returning from sleep");
  lastWakeTime = millis();


}
void wake()
{
  // apparently the uart takes a while to reconfigure on waking up
   Serial.begin(115200);
  delay(100); // crude debounce
  Serial.println("Waking Up");
}
//KGO_END

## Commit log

2014-09-14 bebl_v2 initial commit
    [bebl_v2.sch, bebl_v2_rtc.sch]
2014-09-14 bebl_v2 work in progress
    [bebl_v2.sch]
2014-10-13 LED driver reference circuits added
    [LED_Driver.sch, bebl_v2.sch]
2014-10-22 work in progress
    [bebl_v2.sch]
2014-10-26 bebl_v2 initial 3d mockup
    [bebl_v2.kicad_pcb, smt_batt_clip.stl, smt_batt_clip_Keystone 82.stl]
2014-10-27 bebl_v2 3d mockup of 2 separate boards
    [bebl_v2.kicad_pcb, bebl_v2.sch]
2014-10-28 working on case for bebl_v2
    [bebl_v2 (led).kicad_pcb, bebl_v2 (main).kicad_pcb, bebl_v2.sch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]
2014-10-28 bebl_v2 3d of housing, work in progress
    [bebl_v2 (led).kicad_pcb, bebl_v2 (main).kicad_pcb, bebl_v2.kicad_pcb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]
2014-10-29 bebl_v2 track layout, work in progress
    [bebl_v2.kicad_pcb, bebl_v2.sch]
2014-10-30 bebl_v2 track layout, almost done
    [bebl_v2_box02.fcstd, mainbox.stl, mainpcb.stl]
2014-10-30 created new wedge piece with SP cutout.
    [jwedge.scad]
2014-10-30 jwedge update
    [jwedge.scad]
2014-10-31 minor tweeks to jwedge
    [jwedge.scad]
2014-11-01 bebl_v2 box stl files ready for prototype
    [bebl_v2.kicad_pcb, bebl_v2_box02.fcstd, bebl_v2_box02_XSection.fcstd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]
2014-11-02 made an alternative back cover that does not need to be transparent
    [jcover.scad, jcover.stl, jwedge.scad]
2014-11-03 modified justins version of top cover
    [acover.scad, bebl_v2_box02.fcstd]
2014-11-03 fixed led placement
    [jcover.scad]
2014-11-03 fixed jcover fillet_r and led placement
    [jcover.scad]
2014-11-03 bebl_v2 added new lens cover
    [acover.scad, bebl_v2_box02.fcstd, jcover.scad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]
2014-11-03 bebl_v2 minor update
    [bebl_v2_box02.fcstd]
2014-11-04 changed fillet radius on jwedge
    [jwedge.scad]
2014-11-11 minor update
    [bebl_v2_box02.fcstd]
2014-11-13 BoM modified
    [bebl_v2_BoM_pcb.csv]
2014-11-14 direct LED drive version, work in progress
    [bebl_v2.kicad_pcb, bebl_v2.sch, bebl_v2_BoM_pcb.csv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]
2014-11-15 revised layout for driverless version, in folder bebl_v3. Work in progress
    [bebl_v2.kicad_pcb]
2014-11-16 revised layout for driverless version, in folder bebl_v3. Check PDF files in GERBER folder
    [bebl_v2.dsn, bebl_v2.kicad_pcb]
2014-11-16 modified housing drawing
    [bebl_v2_box03.fcstd]
2014-11-18 corrected accel x/y/z markings on silk legend
    [bebl_v2.kicad_pcb]
2014-12-04 working on transistor based driver for leds
    [bebl_v2.sch, bebl_v2_LED_Driver.sch, bebl_v2_rtc.sch]
2014-12-05 modified schematic for transistor drive
    [LED_brd.sch, bebl_v2.kicad_pcb, bebl_v2.sch]
2014-12-15 new LED drive circuit, work in progress
    [LED_brd.sch, bebl_v2.kicad_pcb, bebl_v2.sch]
2015-01-26 making some progress with new layout
    [LED_brd.sch, bebl_v2.kicad_pcb, bebl_v2.sch]
2015-01-29 layout work in progress
    [bebl_v2.kicad_pcb]
2015-01-30 track layout done. Needs verification
    [LED_Driver.sch, LED_brd.sch, acover.scad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]
2015-02-02 made LED board smaller
    [bebl_v2.kicad_pcb, bebl_v2_a.kicad_pcb]
2015-02-03 bebl_v2 gerbers ready. BoM pending
    [bebl_v2.kicad_pcb, bebl_v2_BoM_pcb.csv]
2015-02-03 footprint errors corrected, BoM ready, but pending seeed format
    [LED_brd.sch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]
2015-02-04 still working on BoM
    [bebl_v2_BoM_seeed.ods]
2015-02-05 Ready to prototype. Gerbers generated
    [PCB Technology Requirement Format V1 for bebl_v2.xlsx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]
2015-03-12 DFM changes to bebl_v2 based on seeed feedback
    [DFM V11_bebl_v2.xlsx, PCB Technology Requirement Format V1 for bebl_v2.xlsx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]
2015-04-07 first test on actual device
2015-04-17 got interrupts working kinda
2015-04-19 bebl_v2 housing mods
    [bebl_v2_box03.fcstd, mainbox_150419.stl, new_topcover_150419.stl]
2015-04-21 top cover CHG led hole thickness reduced
    [bebl_v2_box03.fcstd, new_topcover_150419.stl]
2015-04-22 main box height reduced by 3mm and bottom thickness is 1mm
    [bebl_v2_box03.fcstd, mainbox_150419.stl]
2015-04-23 main box pcb support pillar height reduced by 1mm
    [bebl_v2_box03.fcstd, mainbox_150419.stl]
2015-04-24 fresh 3D model extracted from KiCad
    [LED_Driver.sch, acover.scad, bebl_v2 (led).kicad_pcb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]
2015-04-24 frecad 3d drawing for housing updated
    [bebl_v2_box03.fcstd]
2015-06-12 added image of bebl housing
2015-12-25 added manual calibration code. Updated filter coeff
2015-12-26 added lighting code, first functional brakelight. Need to add sleep and wake code: Kevin??
2015-12-26 updated bandwidth of filters after testing failed. new version tested well.
2015-12-29 add example with power saving sleep. wake with activity or tap
2015-12-31 integrated Kevin's power off and wake code
2015-12-31 added self calibration routine. hold mode on start up to calibrate, rotate 2x on each axis, then double tap to complete
2018-07-15 added Gerber ZIP
    [DFM V11_bebl_v2.xlsx, LED_brd.sch, PCB Technology Requirement Format V1 for bebl_v2.xlsx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]
2019-05-09 added board WRL files to fabricate
    [bebl_v2-B.Cu.gbl, bebl_v2-B.Mask.gbs, bebl_v2-B.Paste.gbp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]
